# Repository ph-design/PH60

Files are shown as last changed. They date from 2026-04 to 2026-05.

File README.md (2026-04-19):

English Version | [中文版](README-zh_CN.md)

**[GitHub Repo](https://github.com/ph-design/PH60) | [Wiki](https://wiki.phdesign.cc/PH60/rev3_multi/) | [Discord](https://discord.gg/8UfQXcefPH) | [Taobao Store](https://shop268559013.taobao.com) | [QQ Group](https://qm.qq.com/q/OY0mIxSRs4) | [Customizer](https://custom.phdesign.cc)**

---

# PH60 Rev.3

**PH60 Rev.3** is a 60% tri-mode mechanical keyboard kit with an FDM 3D-printable case and the PH60 Rev.3 Multi PCB. This revision switches to the NRF52840 MCU with Bluetooth 5.3 and Nordic 2.4 GHz proprietary protocol (TBD), runs [ZMKs](https://github.com/ph-design/zmks) firmware (our fork of ZMK), and redesigns the case for wireless use and multi-layout compatibility.

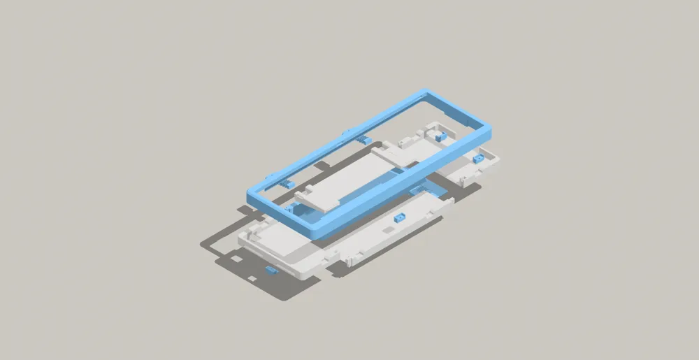
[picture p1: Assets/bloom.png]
PH60 Rev.3 Bloom


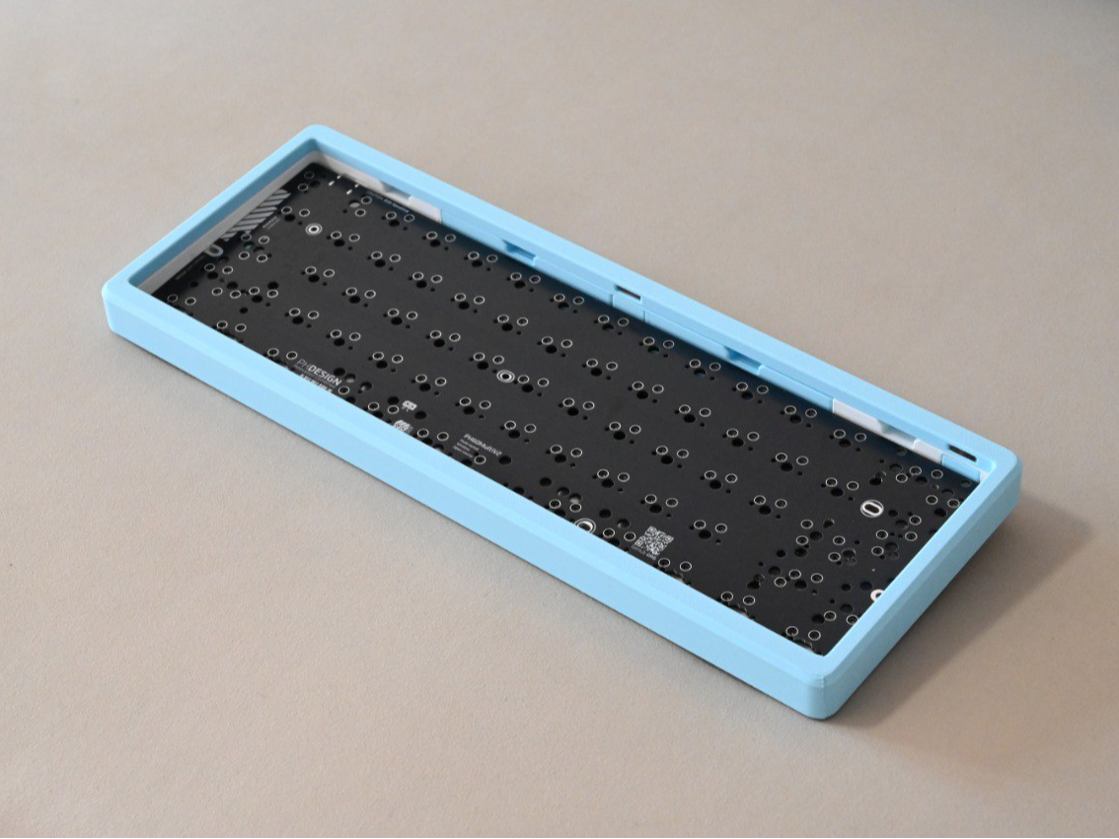
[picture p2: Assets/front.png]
PH60 Rev.3 Front


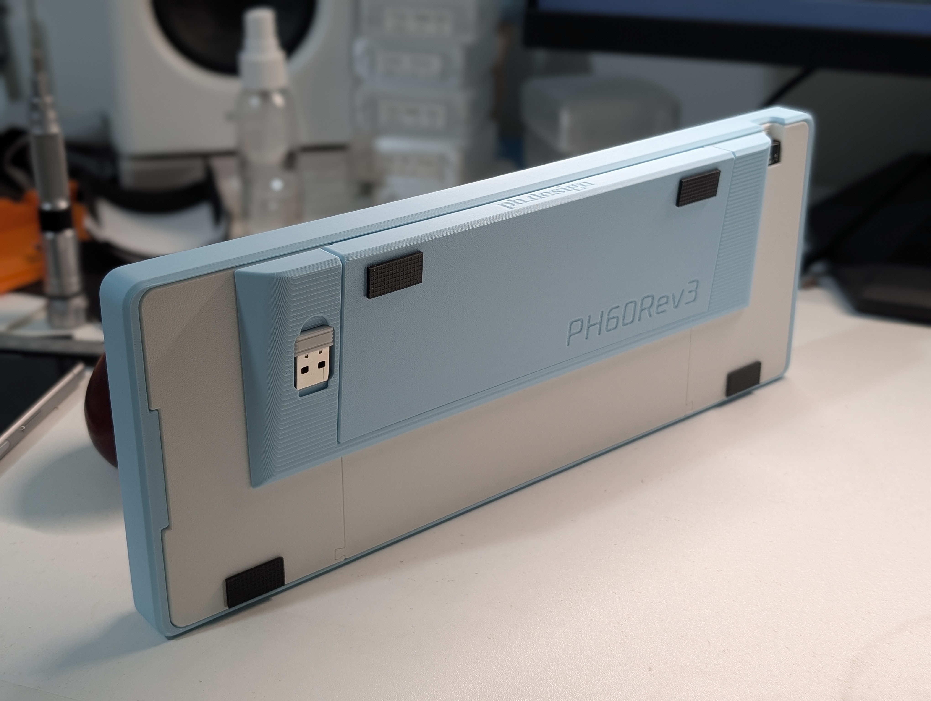
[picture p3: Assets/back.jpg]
PH60 Rev.3 Back


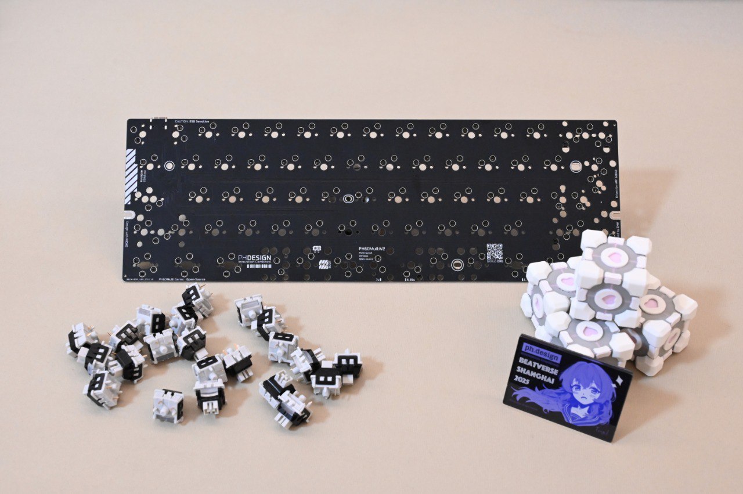
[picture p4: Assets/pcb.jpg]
PH60 Rev.3 PCB


## Features

### PCB

+ [Nordic NRF52840](https://www.nordicsemi.com/products/nrf52840) MCU, Bluetooth 5.3 + 2.4 GHz (TBD).
+ [ZMKs](https://github.com/ph-design/zmks) firmware with [ZMKs Studio](https://zmks.phdesign.cc/) for real-time keymap editing.
+ Multi-layout support — ANSI / ISO / WK / WKL / HHKB, plus split spacebar: 6.25u → 2.75u + 1u + 2.5u, 7u → 3u + 1u + 3u.
+ Battery powered, built-in battery connector.

> **Note on ANSI/ISO variants:** Rev.3 currently only ships the **Multi** layout PCB. The ANSI PCB in this repo is an early prototype with a fundamentally different design approach — there is no standalone ISO version. We may develop dedicated ANSI/ISO variants based on ZMKs in the future.

### Case

+ Designed for FDM 3D printing — printable on any printer with a bed ≥ 256 × 256 mm, no supports required.
+ Magnetic quick-release latches — tool-free disassembly.
+ O-ring gasket plate mount — firm, crisp feel without foam.
+ Modular battery tray and magnet drawers, fits up to 100 × 50 × 5 mm LiPo and 10 × 5 × 5 mm magnets.
+ Locking holder for wireless receivers, compatible with most commercial 2.4 GHz receiver housings.
+ Multiple outer case variants: Standard, WKL, HHKB (6u/7u), and split backspace options.

### Plates

+ Plates available for ANSI, ISO, WK, HHKB (6u/7u), LS64, EC60, and split-key variants.
+ More layouts added over time.

## What's new compared to Rev.2

| | Rev.2 | Rev.3 |
| --- | --- | --- |
| **MCU** | RP2040 | NRF52840 |
| **Connectivity** | USB only | USB + Bluetooth 5.3 + 2.4 GHz (TBD) |
| **Firmware** | QMK + VIA | ZMKs + ZMKs Studio |
| **Power** | USB powered | Battery powered |
| **Split spacebar** | Not supported | 6.25u & 7u split |
| **Case** | 3-piece modular | Magnetic quick-release, O-ring gasket |

## Customizer

Configure your PH60 Rev.3 with live 3D preview at [custom.phdesign.cc](https://custom.phdesign.cc).

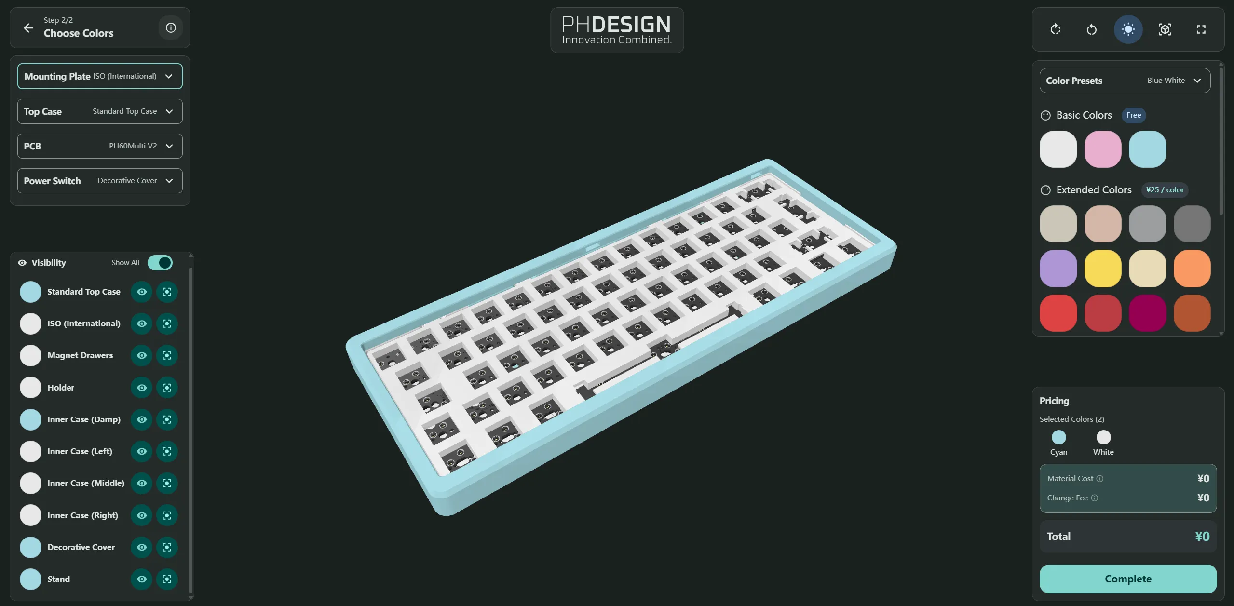
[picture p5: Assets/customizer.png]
PHD Customizer


---

## Project Structure

```
PH60 Rev.3
├── Assets/                         # Preview images
├── Case_Model_Rev3/                # Case 3D model files (STEP)
├── LICENSE
├── PCB_Model_Rev3/                 # PCB 3D model files
├── PCB_Rev3/
│   ├── ANSI/                       # ANSI variant (early prototype)
│   └── Multi/                      # Multi-layout variant (primary)
├── Plates_Rev3/                    # Plate files (STEP)
├── Production/
│   ├── PH60-Rev3-ANSI/             # ANSI production files
│   └── PH60-Rev3-Multi/            # Multi production files
├── README.md
└── README-zh_CN.md
```

## Printing Guide

The case prints well with default FDM settings. Recommended parameters for best results:

| Setting | Recommended | Notes |
| --- | --- | --- |
| Filament | PLA or PETG | High-temp materials increase warp risk |
| Layer height | 0.2 mm | Model designed around 0.2 mm |
| Wall count | 2 walls | — |
| Infill pattern | Gyroid | — |
| Infill density | 15% | — |
| Wall generator | Arachne | Improves print speed |
| Accurate outer wall | Enabled | Reduces visible layer lines |
| Support | Off | Designed for supportless printing |

Make sure the bed is leveled and clean before printing. Use adhesive on long parts like the top cover to prevent warping. Sand and clean prints for a better finish.

## Assembly

### Bill of Materials

| Item | Qty | Notes |
| --- | --- | --- |
| 3D printed case parts | 1 set | PLA or PETG recommended |
| PH60 Rev.3 Multi PCB | 1 | Pre-soldered SMD components |
| MX-compatible switches | 61+ | Varies by layout |
| Keycaps | 1 set | Compatible with 60% layout |
| LiPo battery (optional) | 1 | Recommended: 100 × 50 × 5 mm, Molex 1.25 mm connector |
| Magnets | 8 | Recommended: 10 × 5 × 3 mm, N52 |
| Silicone O-rings | 8 | OD 9 mm, cord 1.5 mm |
| Silicone anti-slip pads | 4 | Recommended: 20 × 10 × 2 mm |

For detailed assembly steps, refer to the [Wiki](https://wiki.phdesign.cc/PH60/rev3_multi/).

## Firmware

### Getting Firmware

- **GitHub Actions**: Download from the [ZMKs config repository](https://github.com/ph-design/ph_lite-zmk-config) Actions artifacts.
- **QQ Group**: Join [512933670](https://qm.qq.com/q/OY0mIxSRs4) for firmware files in group shared folder.

### Flashing Firmware

1. **Enter bootloader**: Press `FN + B + R`, or remove the spacebar keycap and double-tap the `BOOT` pads with tweezers.
2. **Flash**: The keyboard appears as a USB storage device. Copy the `.uf2` file to it — the keyboard reboots automatically.

### Keymap Customization

Visit [ZMKs Studio](https://zmks.phdesign.cc/) for real-time keymap editing.

## FAQ

**Q: Which 3D printers can print the Rev.3 case?**
A: Any FDM printer with a bed ≥ 256 × 256 mm that can print PLA or PETG.

**Q: Which layouts does the Rev.3 case support?**
A: ANSI, ISO, HHKB, WK, WKL, LS64, and EC60 (NIZ electrostatic capacitive). Plate designs are continuously updated.

**Q: Why is there no dedicated ANSI or ISO PCB?**
A: The early ANSI prototype has a fundamentally different design from the Multi PCB. We focused on Multi to support all layouts with a single board. Dedicated variants may come later based on ZMKs.

**Q: What battery and magnet sizes are supported?**
A: Up to 100 × 50 × 5 mm LiPo battery. Magnets: 10 × 5 × 3 mm (N52 recommended). The battery tray and magnet drawers can be modified for other sizes.

## Getting Help

- GitHub Issues: [ph-design/PH60](https://github.com/ph-design/PH60/issues)
- Discord: [discord.gg/phdesign](https://discord.gg/8UfQXcefPH)
- QQ Group: [512933670](https://qm.qq.com/q/OY0mIxSRs4)
- Wiki: [wiki.phdesign.cc](https://wiki.phdesign.cc/)

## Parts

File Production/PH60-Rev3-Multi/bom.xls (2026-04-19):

型号 | 封装 | 位号 | 元件编号
100k | 0402 | R2 | C25741
2k | 0402 | R3 | C4109
1.5p | 0402 | C24 | C1552
PRTR5V0U2X | SOT-143 | D1 | C5158049
1R | 0402 | R5,R6 | C17168
0R | 0402 | R4 | C17168
1u | 0402 | C16,C19,C23 | C52923
TPS2116DRL | SOT-583-8 | U4 | C3235557
FHW0402UC4N7JST | 0402 | L3 | C317941
nRF52840 | Nordic_AQFN-73-1EP_7x7mm_P0.5mm_2_Layer_Board | U2 | C190794
5K1 | 0402 | R7,R8 | C25905
DIODE | D_SOD-123 | D10,D11,D12,D13,D14,D14-1,D15,D16,D17,D18,D19,D2,D20,D21,D22,D23,D24,D25,D26,D27,D28,D29,D3,D30,D31,D32,D33,D34,D35,D36,D37,D38,D39,D4,D40,D41,D42,D43,D44,D45,D46,D47,D48,D49,D5,D50,D51,D52,D53,D54,D55,D56,D57,D58,D59,D6,D60,D61,D62,D63,D64,D65,D66,D67,D7,D8,D9 | C81598
Battery | Molex_PicoBlade_53261-0271_1x02-1MP_P1.25mm_Horizontal | BT1 | C2845379
32.768kHz | Crystal_SMD_3215-2Pin_3.2x1.5mm | X1 | C32346
Crystal_Generic | Crystal_SMD_2016-4Pin_2.0x1.6mm | X2 | C5339095
100n | 0402 | C1,C20,C21,C22 | C1525
12p | 0402 | C10,C14,C15,C8 | C1547
TP4057 | TSOT-23-6 | U1 | C725791
MCL1608S100MT | 0603 | L1,L2 | C51942
100p | 0402 | C4 | C1546
820p | 0402 | C2 | C1523
47n | 0603 | C17 | C1622
2.2u | 0402 | C9 | C12530
LQG15HS15NJ02D | 0402 | L6 | C86059
0.5p | 0402 | C12 | C40459
0.8p | 0402 | C13 | C40459
USB_C_Receptacle_USB2.0_16P | USB-C_16P_HandSolder | J3 | C393939
MX1A | SW_Hotswap_Kailh_MX_Plated_ISOEnter_90deg | S41-1 | C41430893
MX1A | SW_Hotswap_Kailh_MX_Plated_1.00u | S1,S10,S11,S12,S13,S14-1,S14-2,S16,S17,S18,S19,S2,S20,S21,S22,S23,S24,S25,S26,S27,S29,S3,S31,S32,S33,S34,S35,S36,S37,S38,S39,S4,S40,S41,S44,S45,S46,S47,S48,S49,S5,S50,S51,S52,S53,S54,S56,S58-1,S6,S63-1,S7,S8,S9 | C41430893
MX1A | SW_Hotswap_Kailh_MX_Plated_1.50u_90deg | S28 | C41430893
MX1A | SW_Hotswap_Kailh_MX_Plated_7.00u | S60-1 | C41430893
MX1A | SW_Hotswap_Kailh_MX_Plated_1.25u | S29-1,S43,S57,S59,S60,S61,S62,S63,S64,S65 | C41430893
MX1A | SW_Hotswap_Kailh_MX_Plated_1.75u | S30,S55 | C41430893
MX1A | SW_Hotswap_Kailh_MX_Plated_1.50u | S15,S57-1,S59-1,S62-1,S64-1 | C41430893
MX1A | SW_Hotswap_Kailh_MX_Plated_2.25u_90deg | S42 | C41430893
MX1A | SW_Hotswap_Kailh_MX_Plated_2.75u | S55-1,S60-1-B1 | C41430893
MX1A | SW_Hotswap_Kailh_MX_Plated_2.00u | S14 | C41430893
MX1A | SW_Hotswap_Kailh_MX_Plated_2.25u | S43-1,S60-1-A1 | C41430893
MX1A | SW_Hotswap_Kailh_MX_Plated_6.25u | S60-2 | C41430893
MX1A | SW_Hotswap_Kailh_MX_Plated_3.00u | S60-1-A2,S60-1-B2 | C41430893
330k | 0402 | R1 | C25778
4u7 | 0402 | C18,C3,C5,C6,C7 | C23733
4.7u | 0402 | C11 | C23733
Value | Footprint | Designator | NC
Conn_01x02_Pin | PinHeader_1x02_P2.00mm_Vertical | J1,J2 | NC
MX_stab | Stabilizer_Cherry_MX_7.00u | S60-X3 | NC
MX_stab | Stabilizer_Cherry_MX_6.25u | S60-X1 | NC
MX_stab | Stabilizer_Cherry_MX_2.00u | S14-X1,S29-X1,S41-X1,S41-X2,S55-X1,S60-X4,S60-X6 | NC

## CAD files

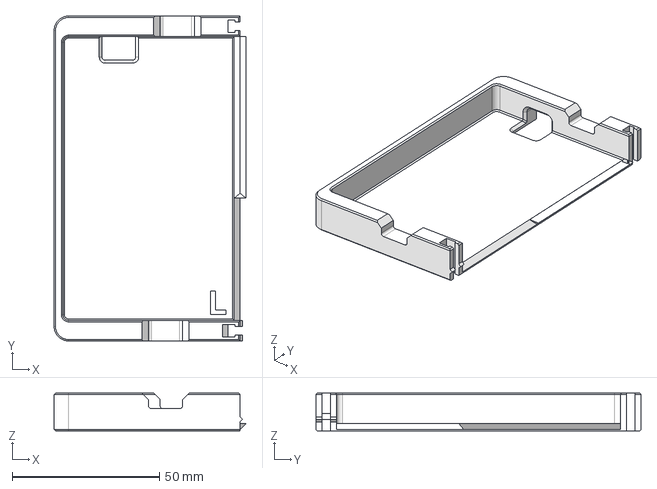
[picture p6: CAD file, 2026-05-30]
Case_Model_Rev3/inner_case_left.step
65.3 x 110.5 x 12.9 mm

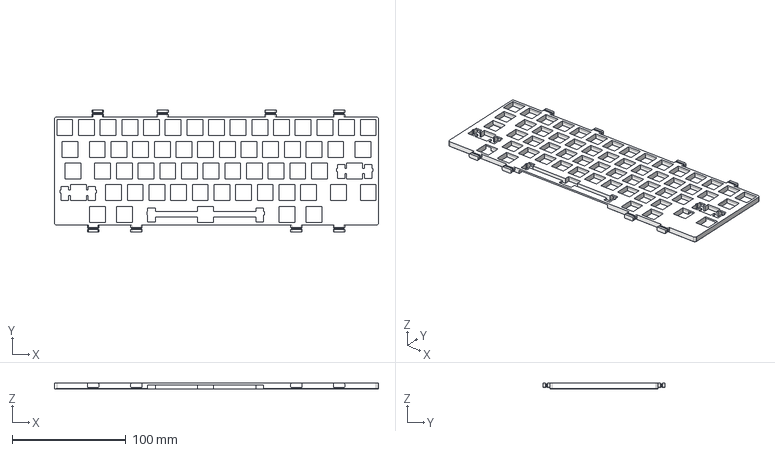
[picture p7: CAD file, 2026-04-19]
Plates_Rev3/plate_6u_hhkb.step
284.7 x 107.3 x 5.00 mm
plate
main_frame

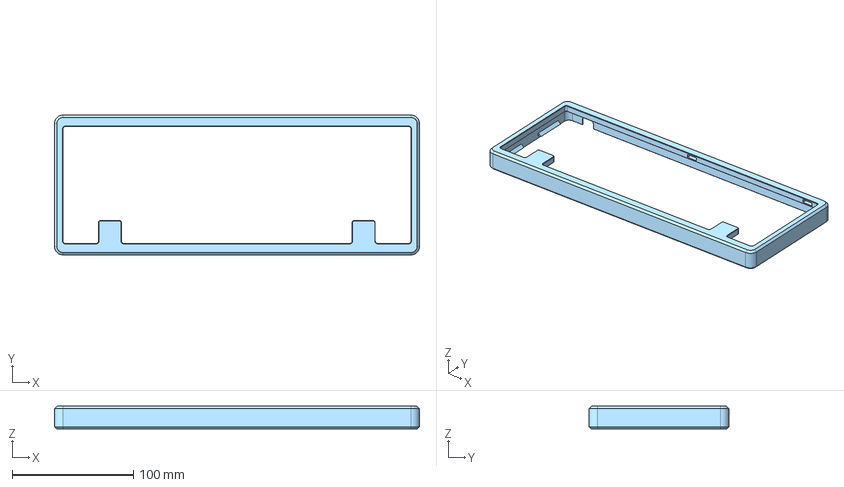
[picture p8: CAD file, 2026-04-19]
Case_Model_Rev3/outer_case_wkl.step
301.4 x 115.5 x 18.7 mm

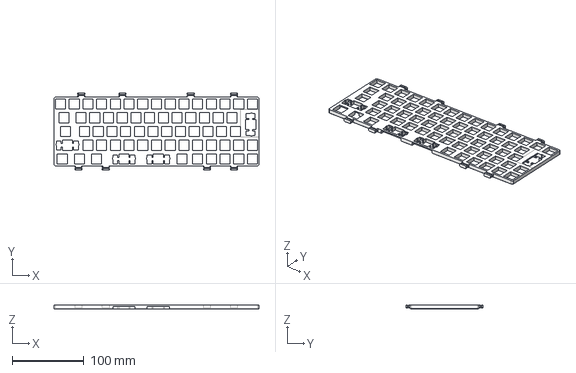
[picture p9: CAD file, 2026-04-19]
Plates_Rev3/plate_ls64_spilt_space_backspace_isoenter.step
284.7 x 107.3 x 5.00 mm

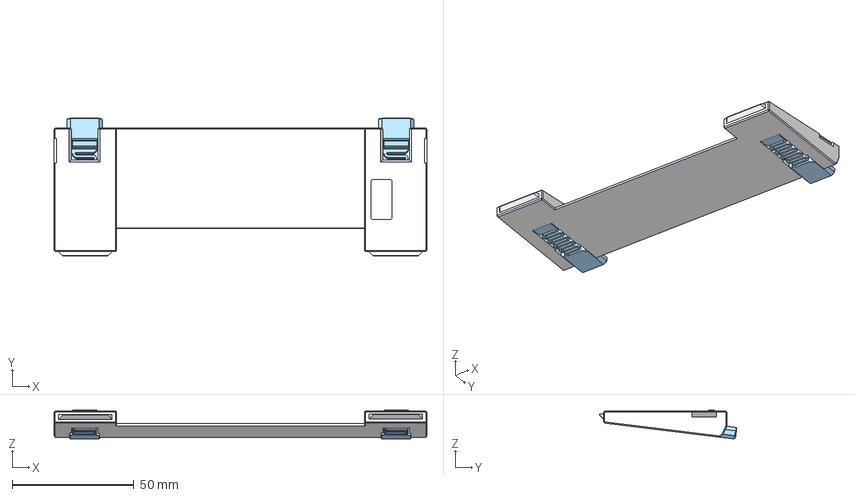
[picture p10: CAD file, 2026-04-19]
Case_Model_Rev3/battery_holder.step
153.1 x 56.5 x 11.9 mm

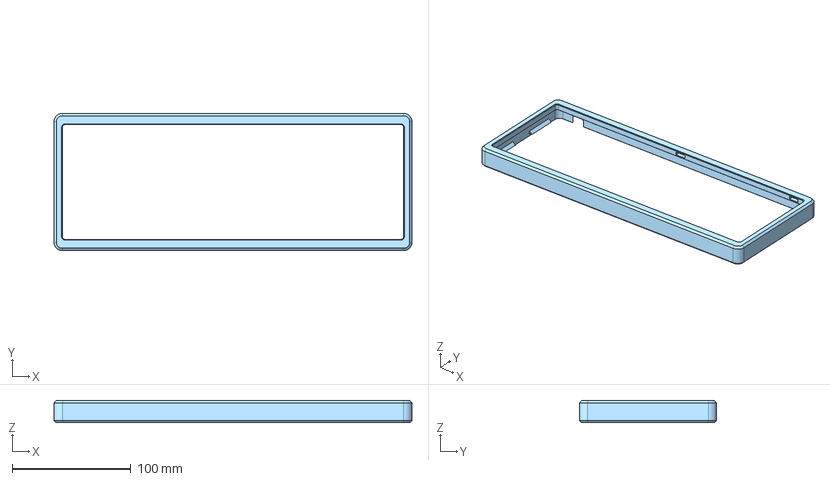
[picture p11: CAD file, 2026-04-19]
Case_Model_Rev3/outer_case.step
301.4 x 115.5 x 18.7 mm

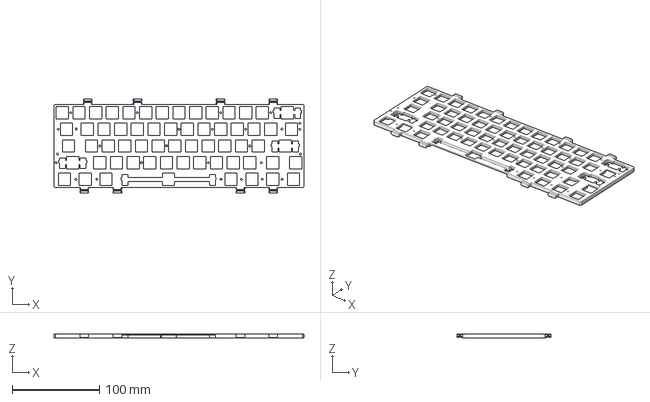
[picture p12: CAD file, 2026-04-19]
Plates_Rev3/plate_h60ec.step
285.7 x 107.3 x 5.00 mm
plate x 2

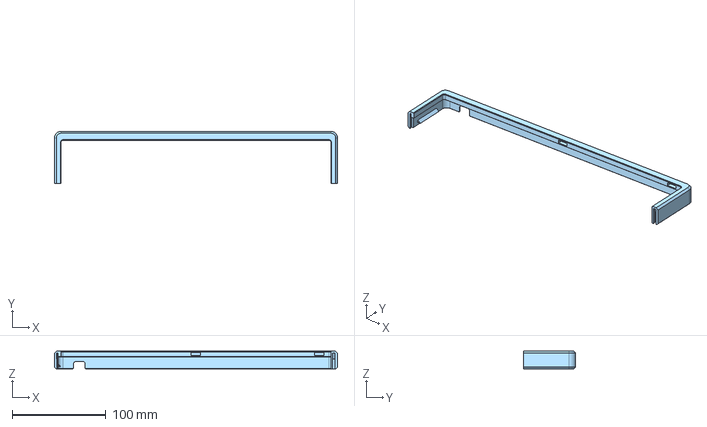
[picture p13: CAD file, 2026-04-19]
Case_Model_Rev3/outer_case_split_f.step
301.4 x 55.7 x 18.7 mm

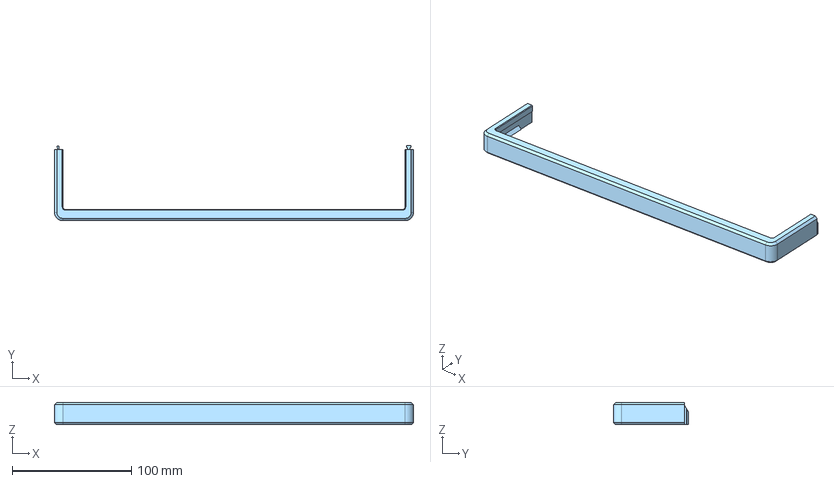
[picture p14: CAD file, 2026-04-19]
Case_Model_Rev3/outer_case_split_b.step
301.4 x 63.3 x 18.7 mm

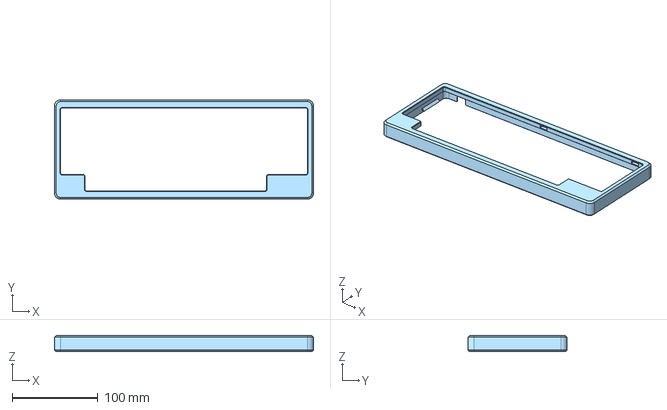
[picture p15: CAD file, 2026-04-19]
Case_Model_Rev3/outer_case_hhkb_6u.step
301.4 x 115.5 x 18.7 mm
plate
main_frame

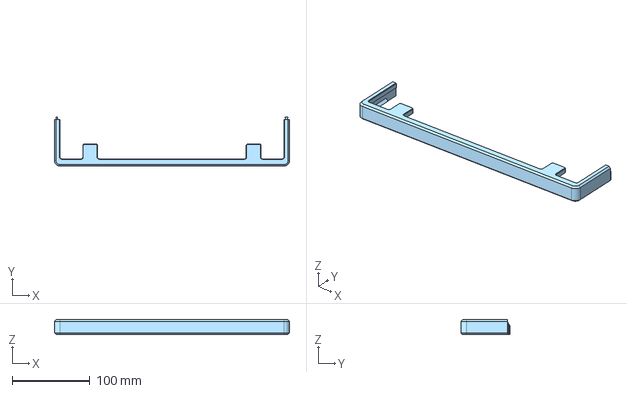
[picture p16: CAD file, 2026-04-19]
Case_Model_Rev3/outer_case_wkl_split_b.step
301.4 x 63.3 x 18.7 mm

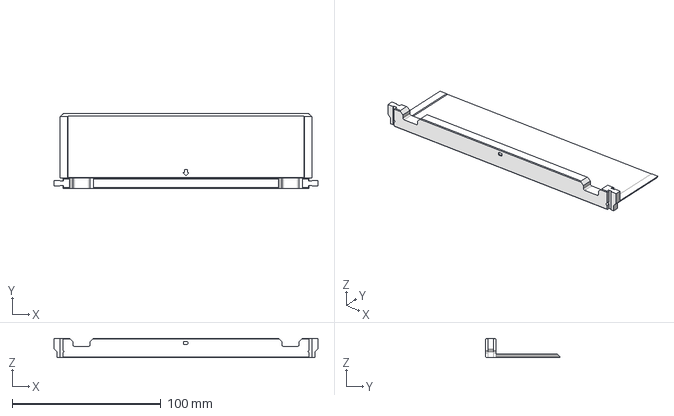
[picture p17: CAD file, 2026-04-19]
Case_Model_Rev3/inner_case_mid.step
177.7 x 50.4 x 12.9 mm

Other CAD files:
Plates_Rev3/plate_wk_split_backspace.step
Plates_Rev3/plate_7u_hhkb.step
Plates_Rev3/plate_ls64_ptg.step
Plates_Rev3/plate_ansi_split_rshift_backspace_space_0.step
Plates_Rev3/plate_ec60_ansi.step
Plates_Rev3/plate_non_shift_63.step
Case_Model_Rev3/inner_case_damp.step
Case_Model_Rev3/inner_case_right.step
Case_Model_Rev3/magnet_drawer.step
Case_Model_Rev3/outer_case_hhkb_6u_split_b.step
Case_Model_Rev3/outer_case_hhkb_7u.step
Case_Model_Rev3/outer_case_hhkb_7u_split_b.step
Case_Model_Rev3/stand.step
Plates_Rev3/plate_7u_hhkb_non_split_backspace.step
Plates_Rev3/plate_ansi.step
Plates_Rev3/plate_ansi_split_backspace_rshift.step
Plates_Rev3/plate_ansi_split_rshift_space_0.step
Plates_Rev3/plate_iso.step
Plates_Rev3/plate_ls64.step
Plates_Rev3/plate_wk.step

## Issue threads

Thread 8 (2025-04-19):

Print Volume

emolitor, 2025-04-19:
The documentation states that you need a 250x250 mm printer but I was able to print the models on a Prusa Core One (250x220mm) simply by printing the large side pieces vertically. While this might by slightly weaker due to layer adhesion I did test versions in PC and PETG and they are holding up fine so far.

nonameCCC, 2025-04-19:
Currently our design of the case was based on Bambu Lab printers, which have 256×256mm of heat bed area, so we gave out the restriction in the document. Smaller device may be able to print the case, but the strength won't be guaranteed.

Closed 2025-04-20.

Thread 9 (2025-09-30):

Plate mount stabilizer clarification

pixil98, 2025-09-30:
After printing this board and talking to MAltmann on Discord, it was clarified that the "thick" plates that are available on [Makerworld](https://makerworld.com/en/models/808113-ph60-a-fully-printable-60-layout-keyboard-case) (and presumably other locations) only support plate mount stabilizers. Can these locations be updated to clarify that they only support plate mount stabilizers? I couldn't find that documented anywhere.

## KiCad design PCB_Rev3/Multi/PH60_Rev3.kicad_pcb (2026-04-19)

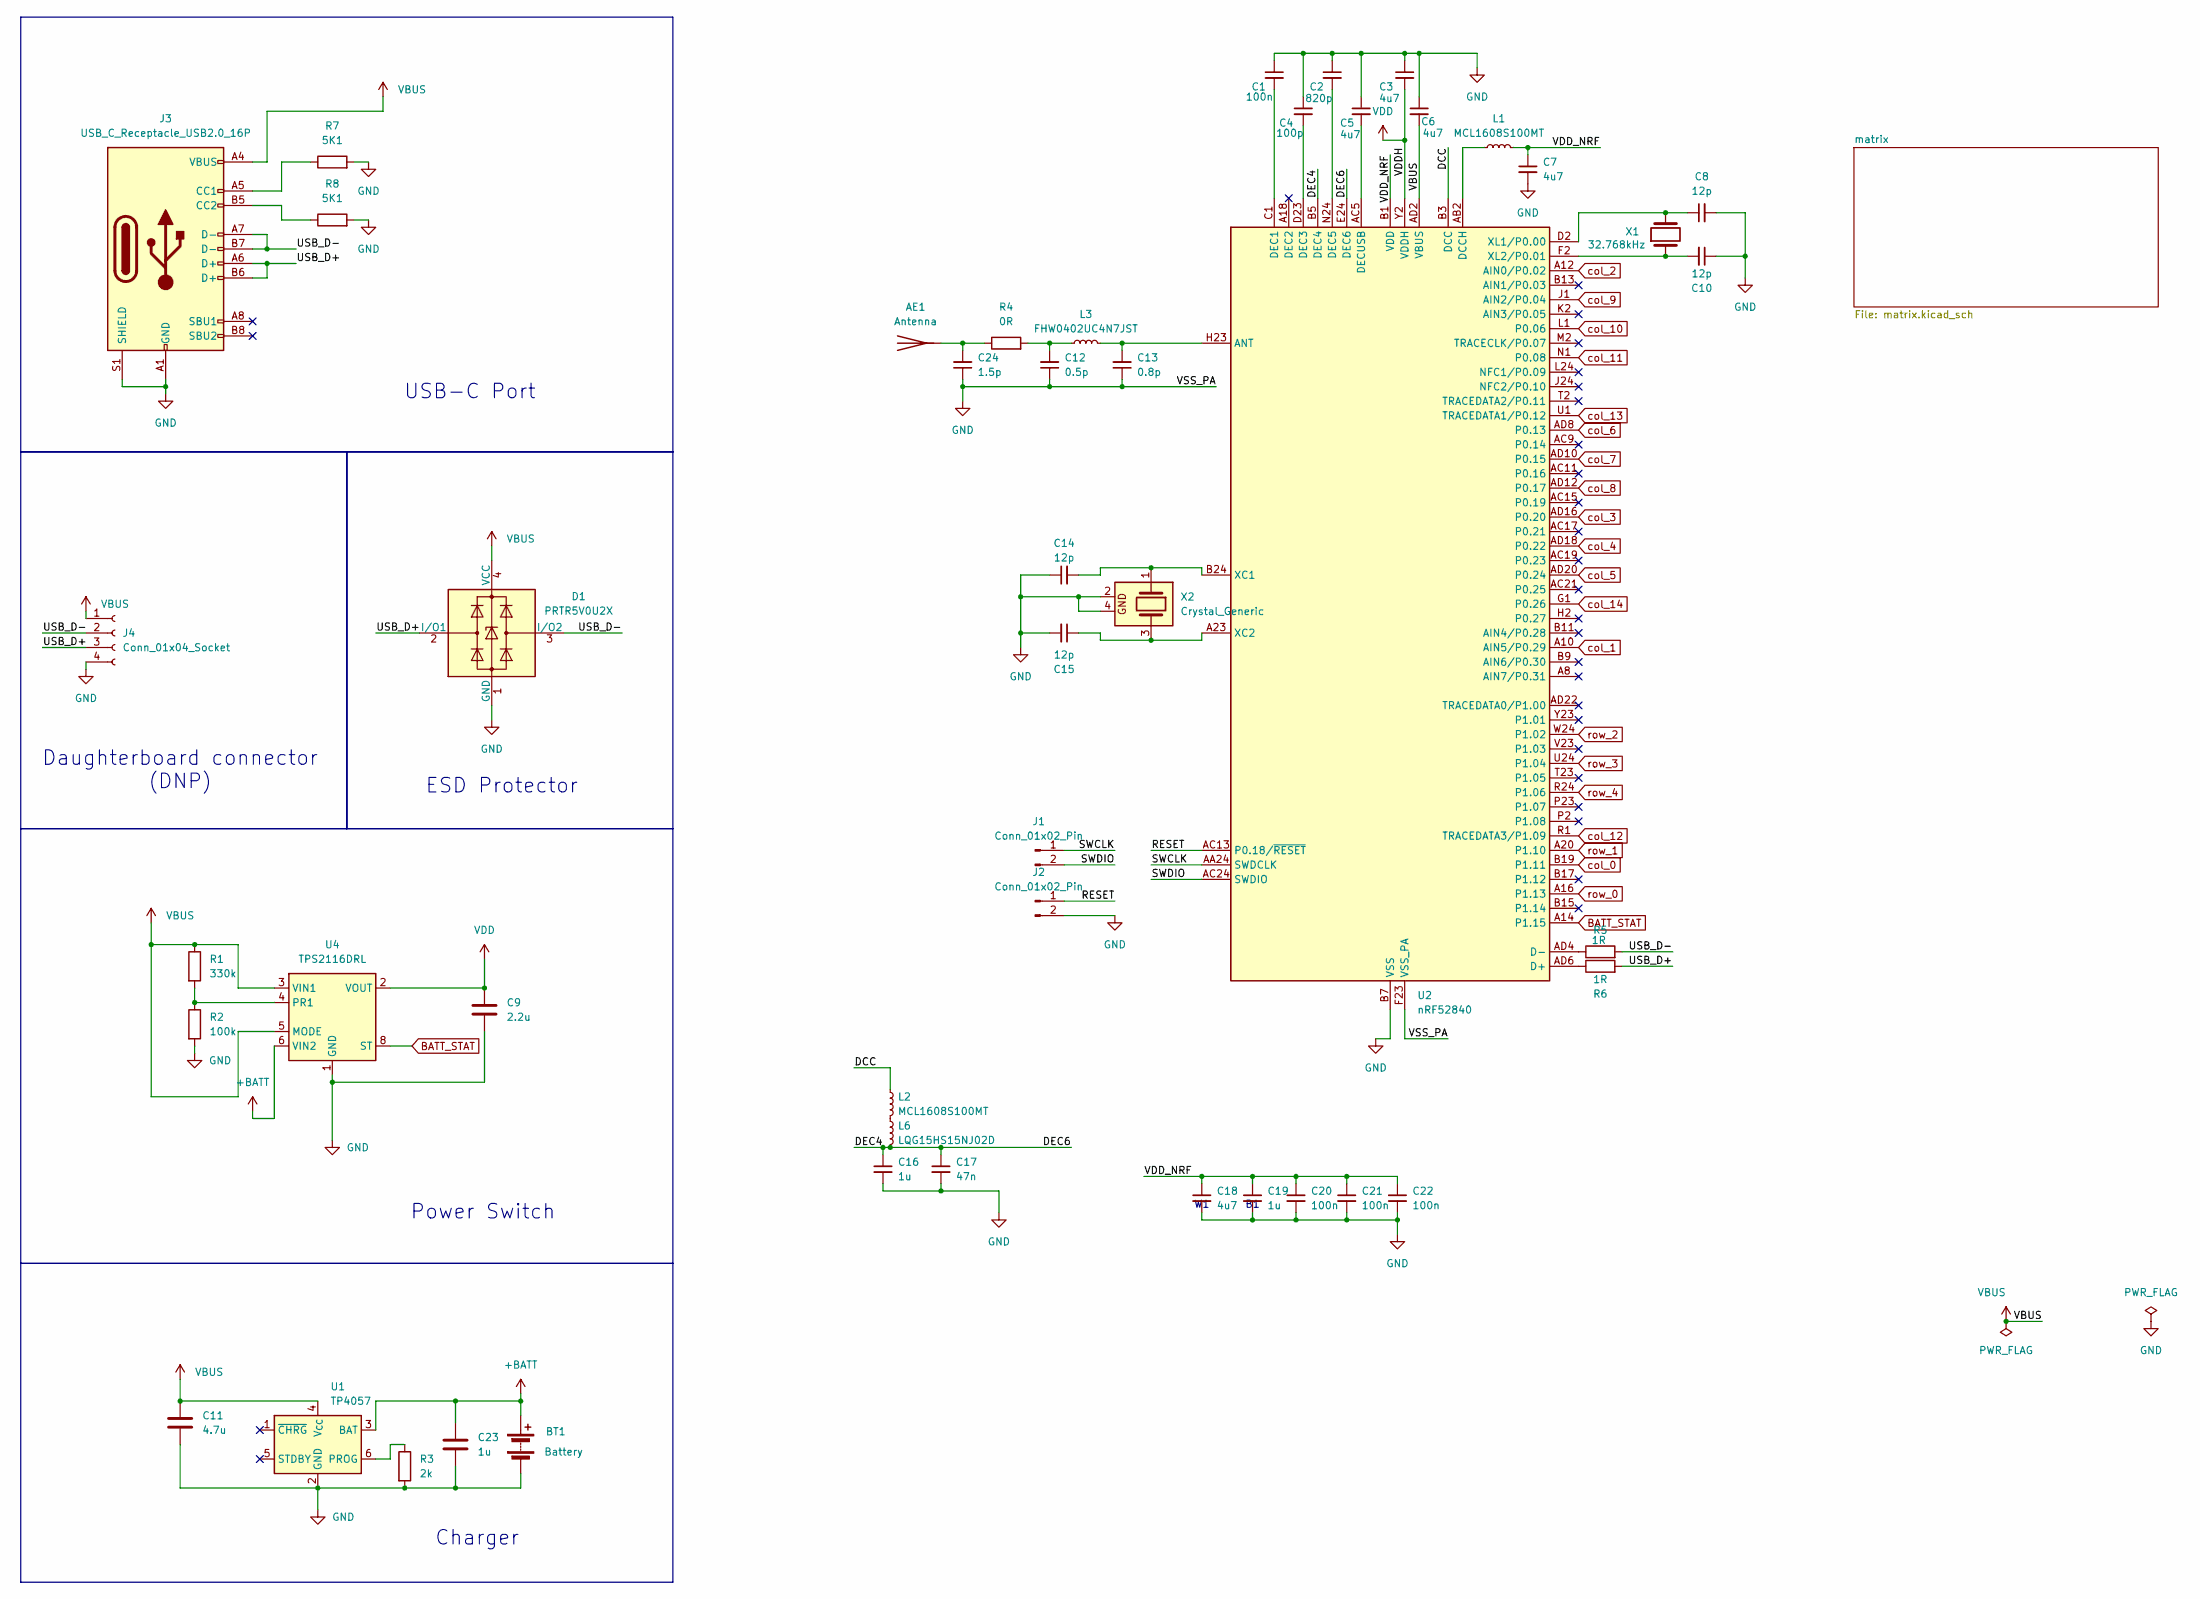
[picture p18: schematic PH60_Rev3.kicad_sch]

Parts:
AE1: Antenna; nrf52_ant_1.6mm
BT1: Battery; Molex_PicoBlade_53261-0271_1x02-1MP_P1.25mm_Horizontal
C1, C20, C21, C22: 100n; C_0402_1005Metric
C2: 820p; C_0402_1005Metric
C3, C5, C6, C7, C18: 4u7; C_0402_1005Metric
C4: 100p; C_0402_1005Metric
C8, C10, C14, C15: 12p; C_0402_1005Metric
C9: 2.2u; C_0402_1005Metric
C11: 4.7u; C_0402_1005Metric
C12: 0.5p; C_0402_1005Metric
C13: 0.8p; C_0402_1005Metric
C16, C19, C23: 1u; C_0402_1005Metric
C17: 47n; C_0603_1608Metric
C24: 1.5p; C_0402_1005Metric
D1: PRTR5V0U2X; SOT-143
J1, J2: Conn_01x02_Pin; PinHeader_1x02_P2.00mm_Vertical
J3: USB_C_Receptacle_USB2.0_16P; USB-C_16P_HandSolder
J4: Conn_01x04_Socket; Molex_Pico-EZmate_78171-0004_1x04-1MP_P1.20mm_Vertical
L1, L2: MCL1608S100MT; L_0603_1608Metric
L3: FHW0402UC4N7JST; L_0402_1005Metric
L6: LQG15HS15NJ02D; L_0402_1005Metric
R1: 330k; R_0402_1005Metric
R2: 100k; R_0402_1005Metric
R3: 2k; R_0402_1005Metric
R4: 0R; C_0402_1005Metric
R5, R6: 1R; C_0402_1005Metric
R7, R8: 5K1; R_0402_1005Metric
U1: TP4057; TSOT-23-6
U2: nRF52840; Nordic_AQFN-73-1EP_7x7mm_P0.5mm_2_Layer_Board
U4: TPS2116DRL; SOT-583-8
X1: 32.768kHz; Crystal_SMD_3215-2Pin_3.2x1.5mm
X2: Crystal_Generic; Crystal_SMD_2016-4Pin_2.0x1.6mm

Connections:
+BATT: BT1.1 (+), C23.1, U1.3 (BAT), U4.6 (VIN2)
/DCC: L2.1, U2.B3 (DCC)
/DEC4: C16.1, C17.1, L6.2, U2.B5 (DEC4), U2.E24 (DEC6)
/RESET: J2.1, U2.AC13 (P0.18/~RESET)
/SWCLK: J1.1, U2.AA24 (SWDCLK)
/SWDIO: J1.2, U2.AC24 (SWDIO)
/USB_D+: D1.2 (I/O1), J3.A6 (D+), J3.B6 (D+), J4.3, R6.2
/USB_D-: D1.3 (I/O2), J3.A7 (D-), J3.B7 (D-), J4.2, R5.2
/VDD_NRF: C7.1, C18.1, C19.1, C20.1, C21.1, C22.1, L1.2, U2.A22 (VDD), U2.AD14 (VDD), U2.AD23 (VDD), U2.B1 (VDD), U2.W1 (VDD)
BATT_STAT: U2.A14 (P1.15), U4.8 (ST)
GND: BT1.2 (-), C1.1, C2.1, C3.1, C4.1, C5.1, C6.1, C7.2, C8.2, C9.2, C10.1, C11.2, C12.1, C13.1, C14.1, C15.2, C16.2, C17.2, C18.2, C19.2, C20.2, C21.2, C22.2, C23.2, C24.1, D1.1 (GND), J2.2, J3.A1 (GND), J3.A12 (GND), J3.B1 (GND), J3.B12 (GND), J3.S1 (SHIELD), J4.4, R2.2, R3.2, R7.2, R8.2, U1.2 (GND), U2.B7 (VSS), U2.EP (VSS), U2.F23 (VSS_PA), U4.1 (GND), X2.2, X2.4
unnamed: AE1.1 (A), C24.2, R4.1
unnamed: C12.2, L3.1, R4.2
unnamed: J3.A5 (CC1), R7.1
unnamed: J3.B5 (CC2), R8.1
unnamed: L2.2, L6.1
unnamed: R3.1, U1.6 (PROG)
unnamed: C13.2, L3.2, U2.H23 (ANT)
unnamed: R6.1, U2.AD6 (D+)
unnamed: R5.1, U2.AD4 (D-)
unnamed: L1.1, U2.AB2 (DCCH)
unnamed: C1.2, U2.C1 (DEC1)
unnamed: C4.2, U2.D23 (DEC3)
unnamed: C2.2, U2.N24 (DEC5)
unnamed: C5.2, U2.AC5 (DECUSB)
unnamed: C14.2, U2.B24 (XC1), X2.1
unnamed: C15.1, U2.A23 (XC2), X2.3
unnamed: C8.1, U2.D2 (XL1/P0.00), X1.2
unnamed: C10.2, U2.F2 (XL2/P0.01), X1.1
unnamed: R1.2, R2.1, U4.4 (PR1)
VBUS: C6.2, C11.1, D1.4 (VCC), J3.A4 (VBUS), J3.A9 (VBUS), J3.B4 (VBUS), J3.B9 (VBUS), J4.1, R1.1, U1.4 (V_{CC}), U2.AD2 (VBUS), U4.3 (VIN1), U4.5 (MODE)
VDD: C3.2, C9.1, U2.Y2 (VDDH), U4.2 (VOUT), U4.7 (VOUT)
col_0: U2.B19 (P1.11); also elsewhere on the board
col_1: U2.A10 (AIN5/P0.29); also elsewhere on the board
col_2: U2.A12 (AIN0/P0.02); also elsewhere on the board
col_3: U2.AD16 (P0.20); also elsewhere on the board
col_4: U2.AD18 (P0.22); also elsewhere on the board
col_5: U2.AD20 (P0.24); also elsewhere on the board
col_6: U2.AD8 (P0.13); also elsewhere on the board
col_7: U2.AD10 (P0.15); also elsewhere on the board
col_8: U2.AD12 (P0.17); also elsewhere on the board
col_9: U2.J1 (AIN2/P0.04); also elsewhere on the board
col_10: U2.L1 (P0.06); also elsewhere on the board
col_11: U2.N1 (P0.08); also elsewhere on the board
col_12: U2.R1 (TRACEDATA3/P1.09); also elsewhere on the board
col_13: U2.U1 (TRACEDATA1/P0.12); also elsewhere on the board
col_14: U2.G1 (P0.26); also elsewhere on the board
row_0: U2.A16 (P1.13); also elsewhere on the board
row_1: U2.A20 (P1.10); also elsewhere on the board
row_2: U2.W24 (P1.02); also elsewhere on the board
row_3: U2.U24 (P1.04); also elsewhere on the board
row_4: U2.R24 (P1.06); also elsewhere on the board

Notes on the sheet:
ESD Protector
USB-C Port
Charger
Daughterboard connector (DNP)
Power Switch

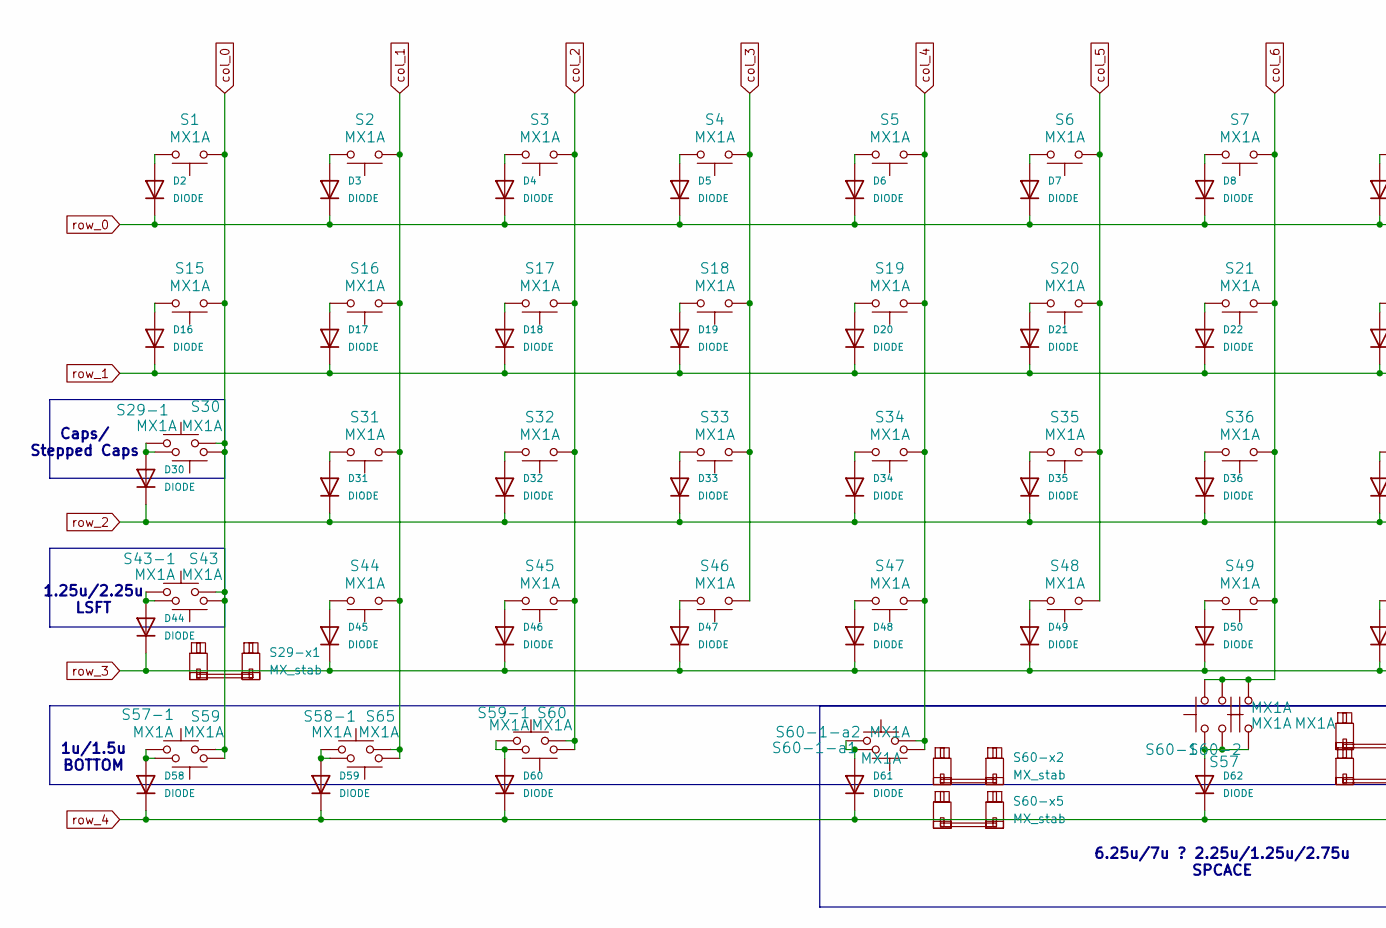
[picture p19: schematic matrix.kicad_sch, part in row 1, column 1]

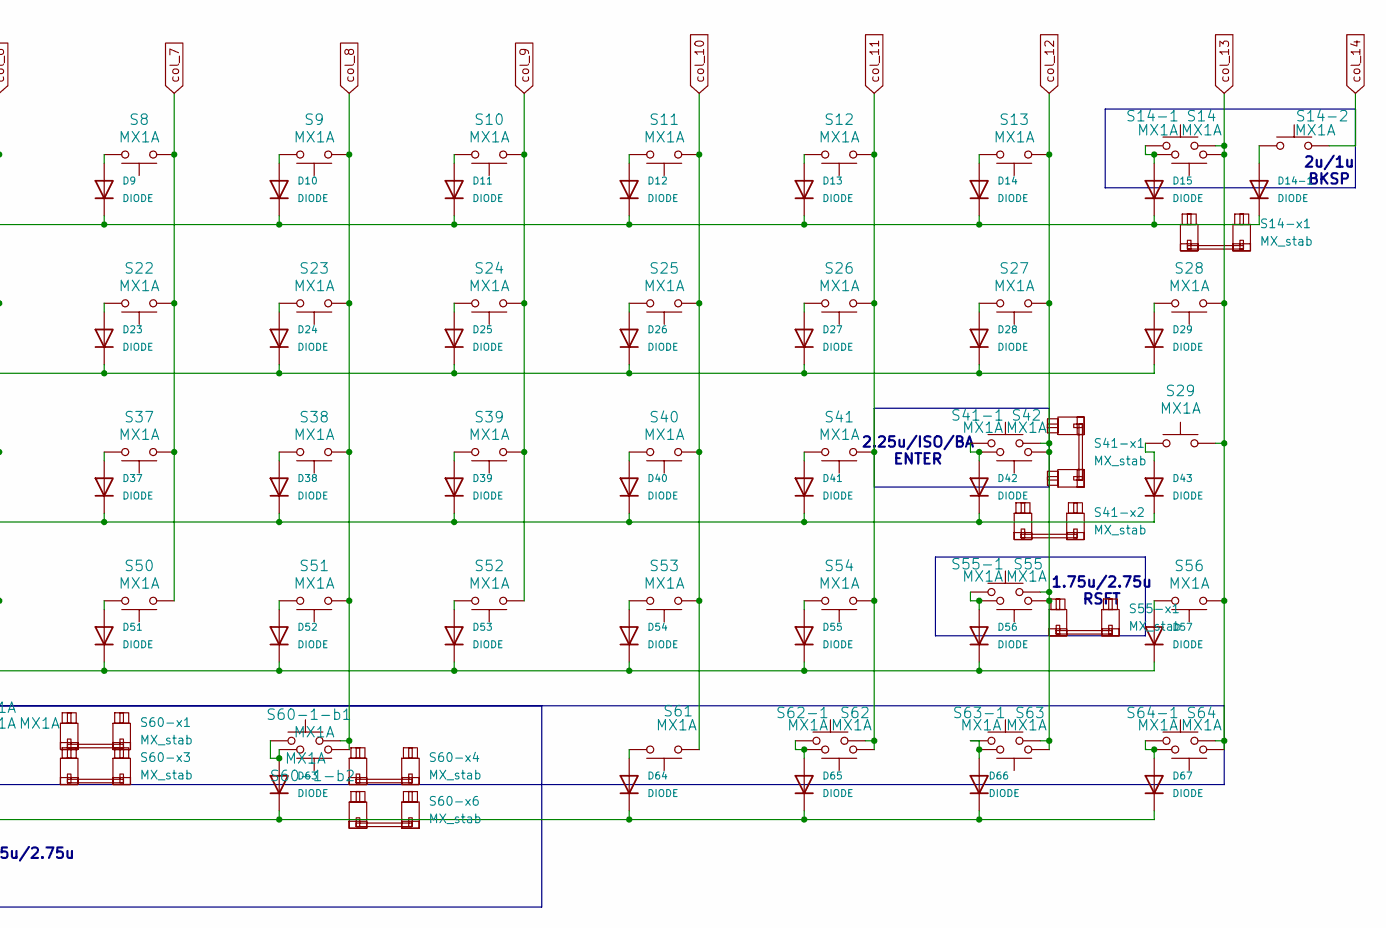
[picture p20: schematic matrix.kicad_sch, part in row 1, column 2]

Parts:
D2, D3, D4, D5, D6, D7, D8, D9, D10, D11, D12, D13, D14, D14-1, D15, D16, D17, D18, D19, D20, D21, D22, D23, D24, D25, D26, D27, D28, D29, D30, D31, D32, D33, D34, D35, D36, D37, D38, D39, D40, D41, D42, D43, D44, D45, D46, D47, D48, D49, D50, D51, D52, D53, D54, D55, D56, D57, D58, D59, D60, D61, D62, D63, D64, D65, D66, D67: DIODE; D_SOD-123
S1, S2, S3, S4, S5, S6, S7, S8, S9, S10, S11, S12, S13, S14-1, S14-2, S16, S17, S18, S19, S20, S21, S22, S23, S24, S25, S26, S27, S29, S31, S32, S33, S34, S35, S36, S37, S38, S39, S40, S41, S44, S45, S46, S47, S48, S49, S50, S51, S52, S53, S54, S56, S58-1, S63-1: MX1A; SW_Hotswap_Kailh_MX_Plated_1.00u
S14: MX1A; SW_Hotswap_Kailh_MX_Plated_2.00u
S14-x1, S29-x1, S41-x1, S41-x2, S55-x1, S60-x2, S60-x4, S60-x5, S60-x6: MX_stab; Stabilizer_Cherry_MX_2.00u
S15, S57-1, S59-1, S62-1, S64-1: MX1A; SW_Hotswap_Kailh_MX_Plated_1.50u
S28: MX1A; SW_Hotswap_Kailh_MX_Plated_1.50u_90deg
S29-1, S43, S57, S59, S60, S61, S62, S63, S64, S65: MX1A; SW_Hotswap_Kailh_MX_Plated_1.25u
S30, S55: MX1A; SW_Hotswap_Kailh_MX_Plated_1.75u
S41-1: MX1A; SW_Hotswap_Kailh_MX_Plated_ISOEnter_90deg
S42: MX1A; SW_Hotswap_Kailh_MX_Plated_2.25u_90deg
S43-1, S60-1-a1: MX1A; SW_Hotswap_Kailh_MX_Plated_2.25u
S55-1, S60-1-b1: MX1A; SW_Hotswap_Kailh_MX_Plated_2.75u
S60-1: MX1A; SW_Hotswap_Kailh_MX_Plated_7.00u
S60-1-a2, S60-1-b2: MX1A; SW_Hotswap_Kailh_MX_Plated_3.00u
S60-2: MX1A; SW_Hotswap_Kailh_MX_Plated_6.25u
S60-x1: MX_stab; Stabilizer_Cherry_MX_6.25u
S60-x3: MX_stab; Stabilizer_Cherry_MX_7.00u

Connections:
unnamed: D2.2 (A), S1.1
unnamed: D3.2 (A), S2.1
unnamed: D4.2 (A), S3.1
unnamed: D5.2 (A), S4.1
unnamed: D6.2 (A), S5.1
unnamed: D7.2 (A), S6.1
unnamed: D8.2 (A), S7.1
unnamed: D9.2 (A), S8.1
unnamed: D10.2 (A), S9.1
unnamed: D11.2 (A), S10.1
unnamed: D12.2 (A), S11.1
unnamed: D13.2 (A), S12.1
unnamed: D14-1.2 (A), S14-2.2
unnamed: D14.2 (A), S13.1
unnamed: D15.2 (A), S14.1, S14-1.2
unnamed: D16.2 (A), S15.1
unnamed: D17.2 (A), S16.1
unnamed: D18.2 (A), S17.1
unnamed: D19.2 (A), S18.1
unnamed: D20.2 (A), S19.1
unnamed: D21.2 (A), S20.1
unnamed: D22.2 (A), S21.1
unnamed: D23.2 (A), S22.1
unnamed: D24.2 (A), S23.1
unnamed: D25.2 (A), S24.1
unnamed: D26.2 (A), S25.1
unnamed: D27.2 (A), S26.1
unnamed: D28.2 (A), S27.1
unnamed: D29.2 (A), S28.1
unnamed: D30.2 (A), S29-1.2, S30.1
unnamed: D31.2 (A), S31.1
unnamed: D32.2 (A), S32.1
unnamed: D33.2 (A), S33.1
unnamed: D34.2 (A), S34.1
unnamed: D35.2 (A), S35.1
unnamed: D36.2 (A), S36.1
unnamed: D37.2 (A), S37.1
unnamed: D38.2 (A), S38.1
unnamed: D39.2 (A), S39.1
unnamed: D40.2 (A), S40.1
unnamed: D41.2 (A), S41.1
unnamed: D42.2 (A), S41-1.2, S42.1
unnamed: D43.2 (A), S29.2
unnamed: D44.2 (A), S43.1, S43-1.2
unnamed: D45.2 (A), S44.1
unnamed: D46.2 (A), S45.1
unnamed: D47.2 (A), S46.1
unnamed: D48.2 (A), S47.1
unnamed: D49.2 (A), S48.1
unnamed: D50.2 (A), S49.1
unnamed: D51.2 (A), S50.1
unnamed: D52.2 (A), S51.1
unnamed: D53.2 (A), S52.1
unnamed: D54.2 (A), S53.1
unnamed: D55.2 (A), S54.1
unnamed: D56.2 (A), S55.1, S55-1.2
unnamed: D57.2 (A), S56.1
unnamed: D58.2 (A), S57-1.1, S59.2
unnamed: D59.2 (A), S58-1.2, S65.1
unnamed: D60.2 (A), S59-1.2, S60.1
unnamed: D61.2 (A), S60-1-a1.1, S60-1-a2.2
unnamed: D62.2 (A), S57.1, S60-1.2, S60-2.2
unnamed: D63.2 (A), S60-1-b1.1, S60-1-b2.2
unnamed: D64.2 (A), S61.1
unnamed: D65.2 (A), S62.1, S62-1.2
unnamed: D66.2 (A), S63.1, S63-1.2
unnamed: D67.2 (A), S64.1, S64-1.2
col_0: S1.2, S15.2, S29-1.1, S30.2, S43.2, S43-1.1, S57-1.2, S59.1; also elsewhere on the board
col_1: S2.2, S16.2, S31.2, S44.2, S58-1.1, S65.2; also elsewhere on the board
col_2: S3.2, S17.2, S32.2, S45.2, S59-1.1, S60.2; also elsewhere on the board
col_3: S4.2, S18.2, S33.2, S46.2; also elsewhere on the board
col_4: S5.2, S19.2, S34.2, S47.2, S60-1-a1.2, S60-1-a2.1; also elsewhere on the board
col_5: S6.2, S20.2, S35.2, S48.2; also elsewhere on the board
col_6: S7.2, S21.2, S36.2, S49.2, S57.2, S60-1.1, S60-2.1; also elsewhere on the board
col_7: S8.2, S22.2, S37.2, S50.2; also elsewhere on the board
col_8: S9.2, S23.2, S38.2, S51.2, S60-1-b1.2, S60-1-b2.1; also elsewhere on the board
col_9: S10.2, S24.2, S39.2, S52.2; also elsewhere on the board
col_10: S11.2, S25.2, S40.2, S53.2, S61.2; also elsewhere on the board
col_11: S12.2, S26.2, S41.2, S54.2, S62.2, S62-1.1; also elsewhere on the board
col_12: S13.2, S27.2, S41-1.1, S42.2, S55.2, S55-1.1, S63.2, S63-1.1; also elsewhere on the board
col_13: S14.2, S14-1.1, S28.2, S29.1, S56.2, S64.2, S64-1.1; also elsewhere on the board
col_14: S14-2.1; also elsewhere on the board
row_0: D2.1 (K), D3.1 (K), D4.1 (K), D5.1 (K), D6.1 (K), D7.1 (K), D8.1 (K), D9.1 (K), D10.1 (K), D11.1 (K), D12.1 (K), D13.1 (K), D14.1 (K), D14-1.1 (K), D15.1 (K); also elsewhere on the board
row_1: D16.1 (K), D17.1 (K), D18.1 (K), D19.1 (K), D20.1 (K), D21.1 (K), D22.1 (K), D23.1 (K), D24.1 (K), D25.1 (K), D26.1 (K), D27.1 (K), D28.1 (K), D29.1 (K); also elsewhere on the board
row_2: D30.1 (K), D31.1 (K), D32.1 (K), D33.1 (K), D34.1 (K), D35.1 (K), D36.1 (K), D37.1 (K), D38.1 (K), D39.1 (K), D40.1 (K), D41.1 (K), D42.1 (K), D43.1 (K); also elsewhere on the board
row_3: D44.1 (K), D45.1 (K), D46.1 (K), D47.1 (K), D48.1 (K), D49.1 (K), D50.1 (K), D51.1 (K), D52.1 (K), D53.1 (K), D54.1 (K), D55.1 (K), D56.1 (K), D57.1 (K); also elsewhere on the board
row_4: D58.1 (K), D59.1 (K), D60.1 (K), D61.1 (K), D62.1 (K), D63.1 (K), D64.1 (K), D65.1 (K), D66.1 (K), D67.1 (K); also elsewhere on the board

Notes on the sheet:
2.25u/ISO/BA ENTER
6.25u/7u ? 2.25u/1.25u/2.75u SPCACE
Caps/ Stepped Caps
2u/1u BKSP
1.75u/2.75u RSFT
1.25u/2.25u LSFT
1u/1.5u BOTTOM

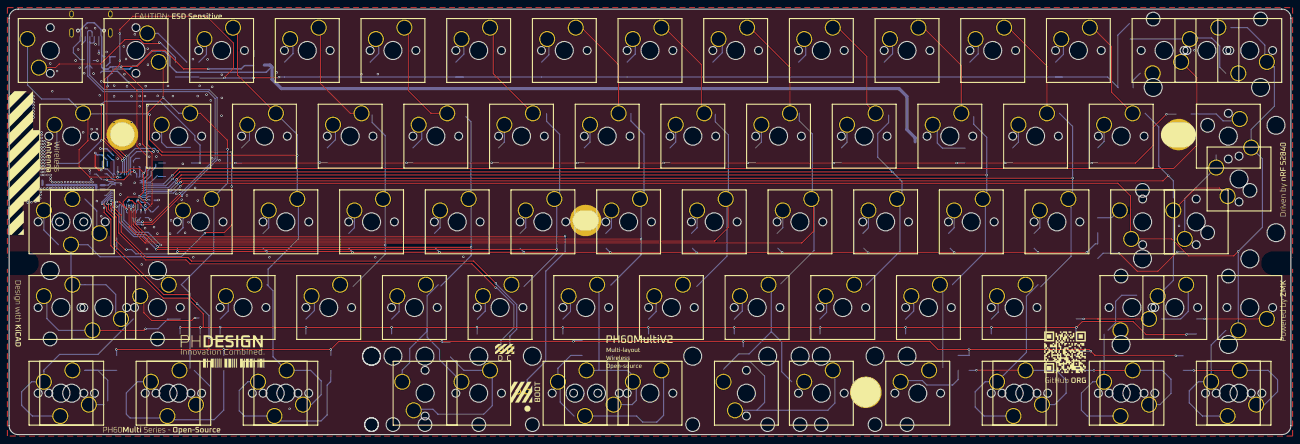
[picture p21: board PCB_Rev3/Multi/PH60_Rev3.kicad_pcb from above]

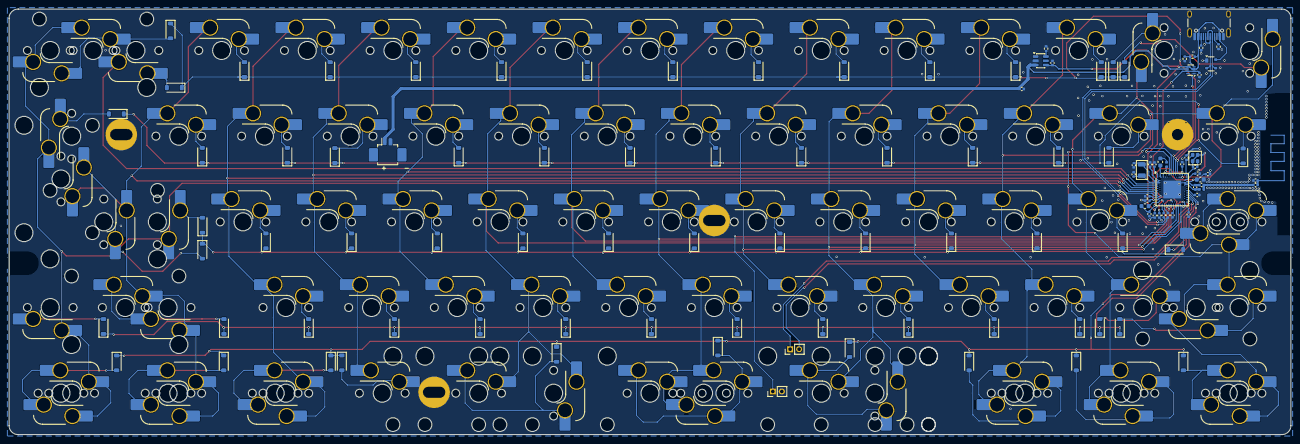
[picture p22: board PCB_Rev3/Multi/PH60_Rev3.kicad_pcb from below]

Board: 2 copper layers, 285.0 x 94.6 mm, 213 parts (114 on the bottom side), 119 nets.

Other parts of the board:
HOLE: VAL**; PKRH
HOLE#2, HOLE#6: VAL**; PKRH
HOLE#3, HOLE#5: VAL**; PKRHSL
HOLE#4: VAL**; PKRHC

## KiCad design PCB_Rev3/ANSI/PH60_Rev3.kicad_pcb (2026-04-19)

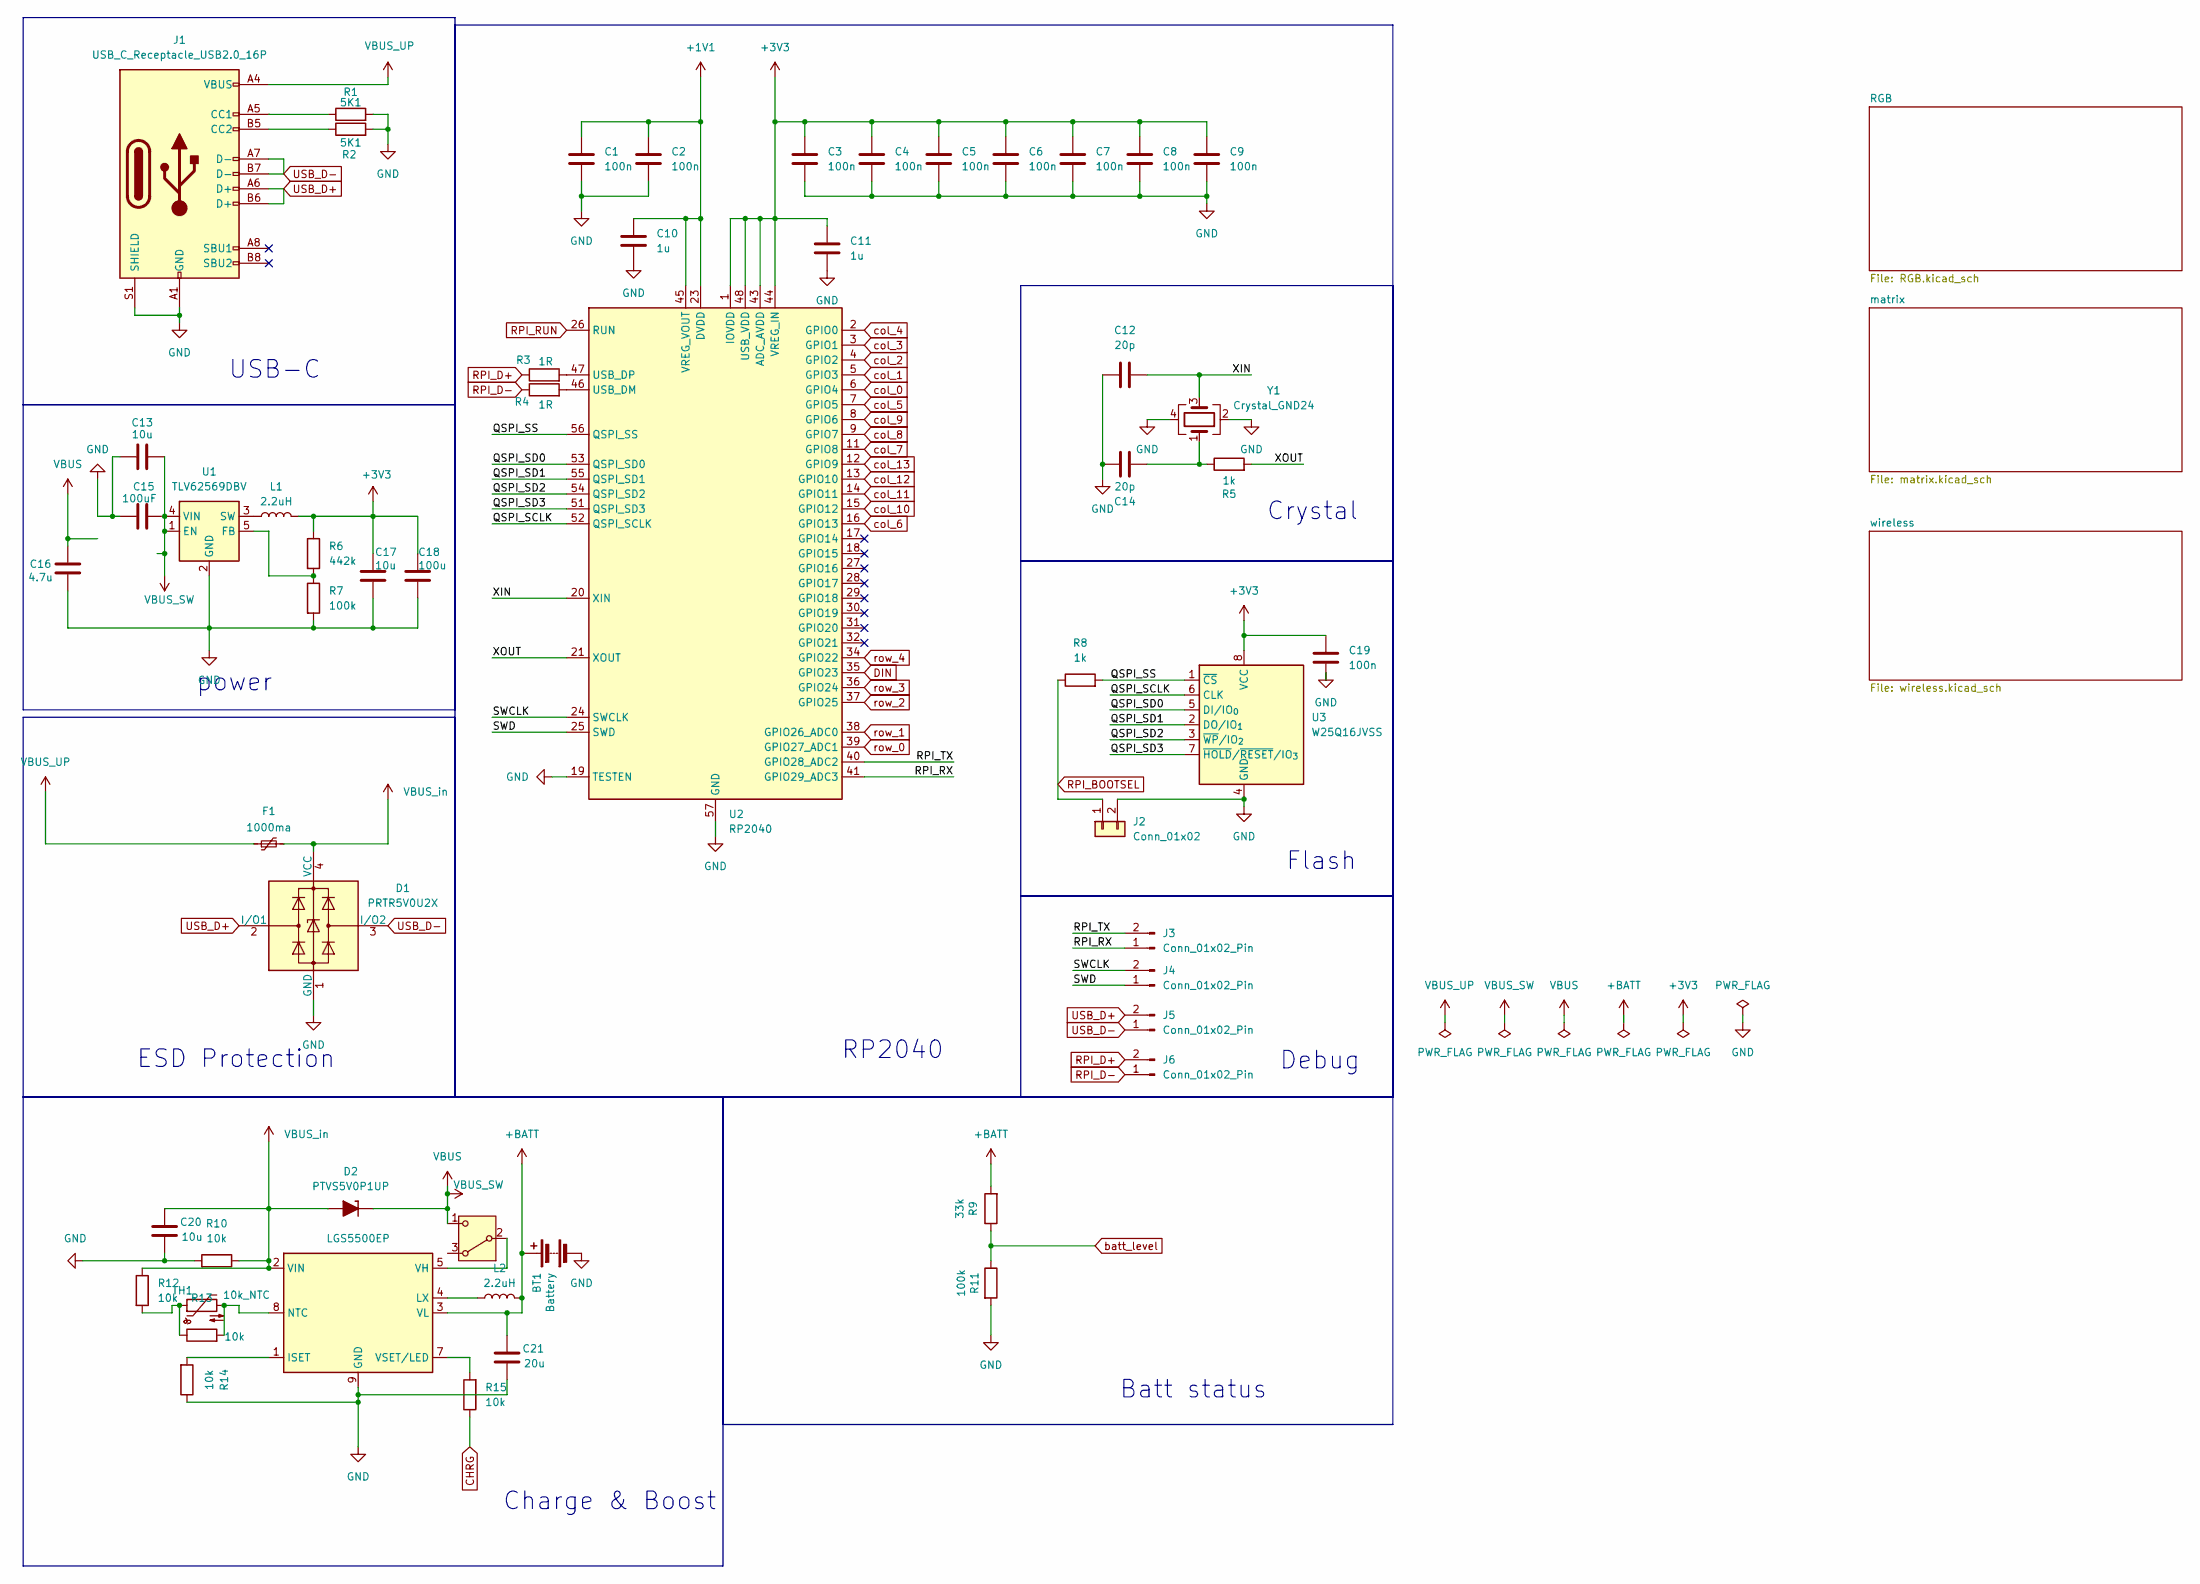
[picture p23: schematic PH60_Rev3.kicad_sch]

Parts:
BT1: Battery; Molex_PicoBlade_53261-0271_1x02-1MP_P1.25mm_Horizontal
C1, C2, C3, C4, C5, C6, C7, C8, C9, C19: 100n; C_0402_1005Metric
C10, C11: 1u; C_0402_1005Metric
C12, C14: 20p; C_0402_1005Metric
C13, C17, C20: 10u; C_0402_1005Metric
C15: 100uF; C_1206_3216Metric
C16: 4.7u; C_0402_1005Metric
C18: 100u; C_0402_1005Metric
C21: 20u; C_0402_1005Metric
D1: PRTR5V0U2X; SOT-143
D2: PTVS5V0P1UP; D_SOD-882_DFN1006-2
F1: 1000ma; Fuse_0805_2012Metric
J1: USB_C_Receptacle_USB2.0_16P; USB-C_16P_HandSolder
J2: Conn_01x02; PinHeader_1x02_P2.54mm_Vertical
J3, J4, J5: Conn_01x02_Pin; PinHeader_1x02_P2.00mm_Vertical
J6: Conn_01x02_Pin; PinHeader_1x02_P1.27mm_Vertical
L1, L2: 2.2uH; L_Changjiang_FNR252012S
R1, R2: 5K1; R_0402_1005Metric
R3, R4: 1R; R_0402_1005Metric
R5, R8: 1k; R_0402_1005Metric
R6: 442k; R_0402_1005Metric
R7, R11: 100k; R_0402_1005Metric
R9: 33k; R_0402_1005Metric
R10, R12, R13, R14, R15: 10k; R_0402_1005Metric
SW1: SW_SPDT_321; SW_MSK12C02-HB
TH1: 10k_NTC; R_0603
U1: TLV62569DBV; SOT-23-5
U2: RP2040; QFN-56-1EP_7x7mm_P0.4mm_EP3.2x3.2mm
U3: W25Q16JVSS; Winbond_USON-8-1EP_3x2mm_P0.5mm_EP0.2x1.6mm
U4: LGS5500EP; SOIC-8-1EP_3.9x4.9mm_P1.27mm_EP2.41x3.3mm
Y1: Crystal_GND24; Crystal_SMD_3225-4Pin_3.2x2.5mm

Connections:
+1V1: C1.1, C2.1, C10.1, U2.23 (DVDD), U2.45 (VREG_VOUT), U2.50 (DVDD)
+3V3: C3.1, C4.1, C5.1, C6.1, C7.1, C8.1, C9.1, C11.1, C17.1, C18.1, C19.1, L1.2, R6.1, U2.1 (IOVDD), U2.10 (IOVDD), U2.22 (IOVDD), U2.33 (IOVDD), U2.42 (IOVDD), U2.43 (ADC_AVDD), U2.44 (VREG_IN), U2.48 (USB_VDD), U2.49 (IOVDD), U3.8 (VCC); also elsewhere on the board
+BATT: BT1.1 (+), C21.1, L2.2, R9.2, U4.3 (VL)
/QSPI_SCLK: U2.52 (QSPI_SCLK), U3.6 (CLK)
/QSPI_SD0: U2.53 (QSPI_SD0), U3.5 (DI/IO_{0})
/QSPI_SD1: U2.55 (QSPI_SD1), U3.2 (DO/IO_{1})
/QSPI_SD2: U2.54 (QSPI_SD2), U3.3 (~WP/IO_{2})
/QSPI_SD3: U2.51 (QSPI_SD3), U3.7 (~HOLD/~RESET/IO_{3})
/QSPI_SS: R8.2, U2.56 (QSPI_SS), U3.1 (~CS)
/RPI_RX: J3.1, U2.41 (GPIO29_ADC3)
/RPI_TX: J3.2, U2.40 (GPIO28_ADC2)
/SWCLK: J4.2, U2.24 (SWCLK)
/SWD: J4.1, U2.25 (SWD)
/XIN: C12.1, U2.20 (XIN), Y1.3
/XOUT: R5.2, U2.21 (XOUT)
CHRG: R15.1; also elsewhere on the board
DIN: U2.35 (GPIO23); also elsewhere on the board
GND: BT1.2 (-), C1.2, C2.2, C3.2, C4.2, C5.2, C6.2, C7.2, C8.2, C9.2, C10.2, C11.2, C12.2, C13.1, C14.2, C15.1, C16.2, C17.2, C18.2, C19.2, C20.2, C21.2, D1.1 (GND), J1.A1 (GND), J1.A12 (GND), J1.B1 (GND), J1.B12 (GND), J1.S1 (SHIELD), J2.2, R1.2, R2.2, R7.2, R10.2, R11.2, R14.1, U1.2 (GND), U2.19 (TESTEN), U2.57 (GND), U3.4 (GND), U4.9 (GND), Y1.2, Y1.4; also elsewhere on the board
unnamed: C14.1, R5.1, Y1.1
unnamed: J1.A5 (CC1), R1.1
unnamed: J1.B5 (CC2), R2.1
unnamed: R12.2, R13.1, TH1.1
unnamed: SW1.2 (B), U4.5 (VH)
unnamed: R6.2, R7.1, U1.5 (FB)
unnamed: L1.1, U1.3 (SW)
unnamed: R4.2, U2.46 (USB_DM)
unnamed: R3.2, U2.47 (USB_DP)
unnamed: R14.2, U4.1 (ISET)
unnamed: L2.1, U4.4 (LX)
unnamed: R13.2, TH1.2, U4.8 (NTC)
unnamed: R15.2, U4.7 (VSET/LED)
RPI_BOOTSEL: J2.1, R8.1; also elsewhere on the board
RPI_D+: J6.2, R3.1; also elsewhere on the board
RPI_D-: J6.1, R4.1; also elsewhere on the board
RPI_RUN: U2.26 (RUN); also elsewhere on the board
USB_D+: D1.2 (I/O1), J1.A6 (D+), J1.B6 (D+), J5.2; also elsewhere on the board
USB_D-: D1.3 (I/O2), J1.A7 (D-), J1.B7 (D-), J5.1; also elsewhere on the board
VBUS: C13.2, C15.2, C16.1, D2.1 (K), SW1.1 (C), U1.1 (EN), U1.4 (VIN); also elsewhere on the board
VBUS_UP: F1.1, J1.A4 (VBUS), J1.A9 (VBUS), J1.B4 (VBUS), J1.B9 (VBUS)
VBUS_in: C20.1, D1.4 (VCC), D2.2 (A), F1.2, R10.1, R12.1, U4.2 (VIN)
batt_level: R9.1, R11.1; also elsewhere on the board
col_0: U2.6 (GPIO4); also elsewhere on the board
col_1: U2.5 (GPIO3); also elsewhere on the board
col_2: U2.4 (GPIO2); also elsewhere on the board
col_3: U2.3 (GPIO1); also elsewhere on the board
col_4: U2.2 (GPIO0); also elsewhere on the board
col_5: U2.7 (GPIO5); also elsewhere on the board
col_6: U2.16 (GPIO13); also elsewhere on the board
col_7: U2.11 (GPIO8); also elsewhere on the board
col_8: U2.9 (GPIO7); also elsewhere on the board
col_9: U2.8 (GPIO6); also elsewhere on the board
col_10: U2.15 (GPIO12); also elsewhere on the board
col_11: U2.14 (GPIO11); also elsewhere on the board
col_12: U2.13 (GPIO10); also elsewhere on the board
col_13: U2.12 (GPIO9); also elsewhere on the board
row_0: U2.39 (GPIO27_ADC1); also elsewhere on the board
row_1: U2.38 (GPIO26_ADC0); also elsewhere on the board
row_2: U2.37 (GPIO25); also elsewhere on the board
row_3: U2.36 (GPIO24); also elsewhere on the board
row_4: U2.34 (GPIO22); also elsewhere on the board

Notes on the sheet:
Batt status
ESD Protection
Charge & Boost
USB-C
Crystal
Flash
power
RP2040
Debug

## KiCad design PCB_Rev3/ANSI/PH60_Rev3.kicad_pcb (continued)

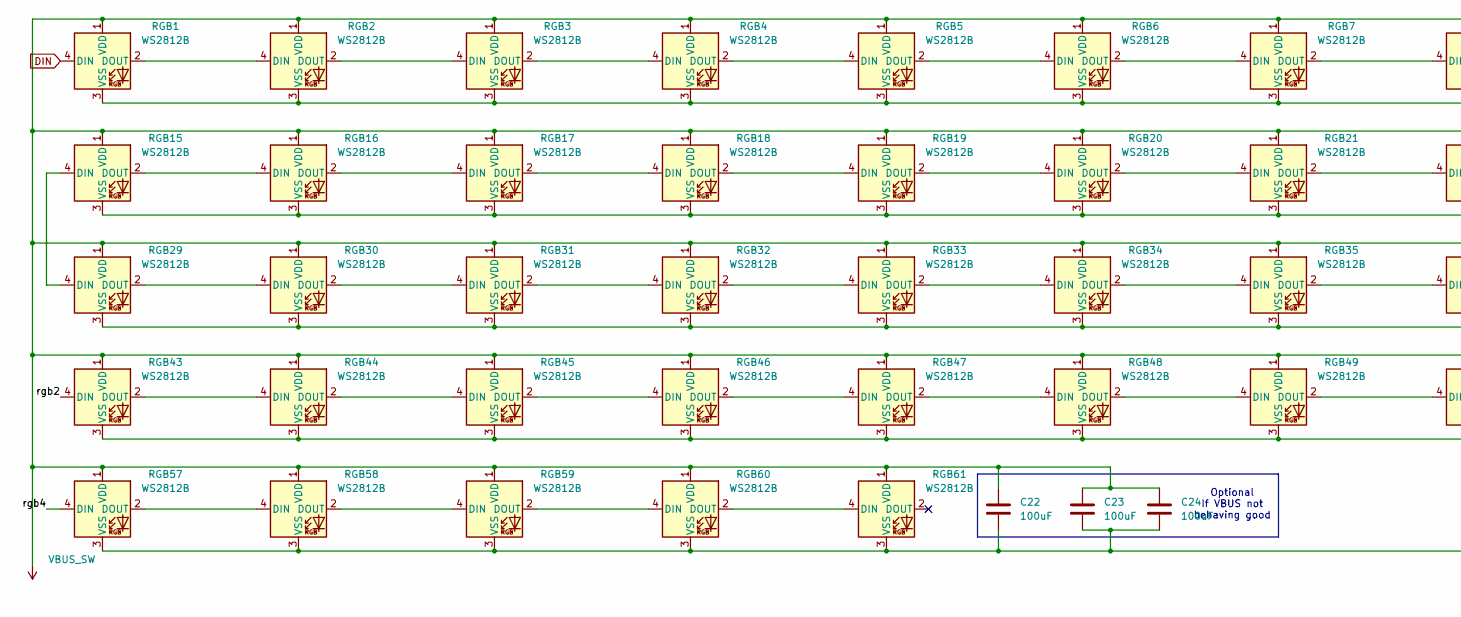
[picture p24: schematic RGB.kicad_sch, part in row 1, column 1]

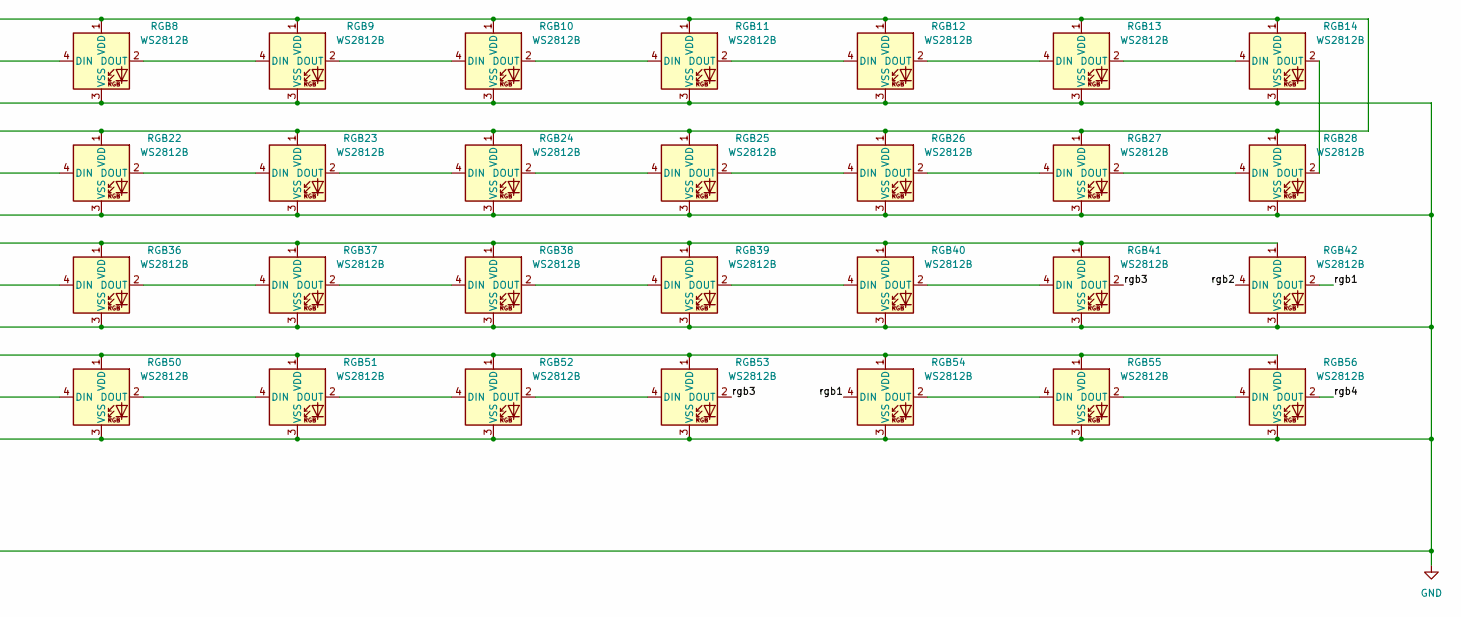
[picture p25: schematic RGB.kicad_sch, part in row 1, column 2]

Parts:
C22, C23, C24: 100uF; C_1206_3216Metric
RGB1, RGB2, RGB3, RGB4, RGB5, RGB6, RGB7, RGB8, RGB9, RGB10, RGB11, RGB12, RGB13, RGB14, RGB15, RGB16, RGB17, RGB18, RGB19, RGB20, RGB21, RGB22, RGB23, RGB24, RGB25, RGB26, RGB27, RGB28, RGB29, RGB30, RGB31, RGB32, RGB33, RGB34, RGB35, RGB36, RGB37, RGB38, RGB39, RGB40, RGB41, RGB42, RGB43, RGB44, RGB45, RGB46, RGB47, RGB48, RGB49, RGB50, RGB51, RGB52, RGB53, RGB54, RGB55, RGB56, RGB57, RGB58, RGB59, RGB60, RGB61: WS2812B; ws2812b_6028

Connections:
/RGB/rgb1: RGB42.2 (DOUT), RGB54.4 (DIN)
/RGB/rgb2: RGB42.4 (DIN), RGB43.4 (DIN)
/RGB/rgb3: RGB41.2 (DOUT), RGB53.2 (DOUT)
/RGB/rgb4: RGB56.2 (DOUT), RGB57.4 (DIN)
DIN: RGB1.4 (DIN); also elsewhere on the board
GND: C22.2, C23.2, C24.2, RGB1.3 (VSS), RGB2.3 (VSS), RGB3.3 (VSS), RGB4.3 (VSS), RGB5.3 (VSS), RGB6.3 (VSS), RGB7.3 (VSS), RGB8.3 (VSS), RGB9.3 (VSS), RGB10.3 (VSS), RGB11.3 (VSS), RGB12.3 (VSS), RGB13.3 (VSS), RGB14.3 (VSS), RGB15.3 (VSS), RGB16.3 (VSS), RGB17.3 (VSS), RGB18.3 (VSS), RGB19.3 (VSS), RGB20.3 (VSS), RGB21.3 (VSS), RGB22.3 (VSS), RGB23.3 (VSS), RGB24.3 (VSS), RGB25.3 (VSS), RGB26.3 (VSS), RGB27.3 (VSS), RGB28.3 (VSS), RGB29.3 (VSS), RGB30.3 (VSS), RGB31.3 (VSS), RGB32.3 (VSS), RGB33.3 (VSS), RGB34.3 (VSS), RGB35.3 (VSS), RGB36.3 (VSS), RGB37.3 (VSS), RGB38.3 (VSS), RGB39.3 (VSS), RGB40.3 (VSS), RGB41.3 (VSS), RGB42.3 (VSS), RGB43.3 (VSS), RGB44.3 (VSS), RGB45.3 (VSS), RGB46.3 (VSS), RGB47.3 (VSS), RGB48.3 (VSS), RGB49.3 (VSS), RGB50.3 (VSS), RGB51.3 (VSS), RGB52.3 (VSS), RGB53.3 (VSS), RGB54.3 (VSS), RGB55.3 (VSS), RGB56.3 (VSS), RGB57.3 (VSS), RGB58.3 (VSS), RGB59.3 (VSS), RGB60.3 (VSS), RGB61.3 (VSS); also elsewhere on the board
unnamed: RGB1.2 (DOUT), RGB2.4 (DIN)
unnamed: RGB2.2 (DOUT), RGB3.4 (DIN)
unnamed: RGB3.2 (DOUT), RGB4.4 (DIN)
unnamed: RGB4.2 (DOUT), RGB5.4 (DIN)
unnamed: RGB5.2 (DOUT), RGB6.4 (DIN)
unnamed: RGB6.2 (DOUT), RGB7.4 (DIN)
unnamed: RGB7.2 (DOUT), RGB8.4 (DIN)
unnamed: RGB8.2 (DOUT), RGB9.4 (DIN)
unnamed: RGB9.2 (DOUT), RGB10.4 (DIN)
unnamed: RGB10.2 (DOUT), RGB11.4 (DIN)
unnamed: RGB11.2 (DOUT), RGB12.4 (DIN)
unnamed: RGB12.2 (DOUT), RGB13.4 (DIN)
unnamed: RGB13.2 (DOUT), RGB14.4 (DIN)
unnamed: RGB14.2 (DOUT), RGB28.2 (DOUT)
unnamed: RGB15.4 (DIN), RGB29.4 (DIN)
unnamed: RGB15.2 (DOUT), RGB16.4 (DIN)
unnamed: RGB16.2 (DOUT), RGB17.4 (DIN)
unnamed: RGB17.2 (DOUT), RGB18.4 (DIN)
unnamed: RGB18.2 (DOUT), RGB19.4 (DIN)
unnamed: RGB19.2 (DOUT), RGB20.4 (DIN)
unnamed: RGB20.2 (DOUT), RGB21.4 (DIN)
unnamed: RGB21.2 (DOUT), RGB22.4 (DIN)
unnamed: RGB22.2 (DOUT), RGB23.4 (DIN)
unnamed: RGB23.2 (DOUT), RGB24.4 (DIN)
unnamed: RGB24.2 (DOUT), RGB25.4 (DIN)
unnamed: RGB25.2 (DOUT), RGB26.4 (DIN)
unnamed: RGB26.2 (DOUT), RGB27.4 (DIN)
unnamed: RGB27.2 (DOUT), RGB28.4 (DIN)
unnamed: RGB29.2 (DOUT), RGB30.4 (DIN)
unnamed: RGB30.2 (DOUT), RGB31.4 (DIN)
unnamed: RGB31.2 (DOUT), RGB32.4 (DIN)
unnamed: RGB32.2 (DOUT), RGB33.4 (DIN)
unnamed: RGB33.2 (DOUT), RGB34.4 (DIN)
unnamed: RGB34.2 (DOUT), RGB35.4 (DIN)
unnamed: RGB35.2 (DOUT), RGB36.4 (DIN)
unnamed: RGB36.2 (DOUT), RGB37.4 (DIN)
unnamed: RGB37.2 (DOUT), RGB38.4 (DIN)
unnamed: RGB38.2 (DOUT), RGB39.4 (DIN)
unnamed: RGB39.2 (DOUT), RGB40.4 (DIN)
unnamed: RGB40.2 (DOUT), RGB41.4 (DIN)
unnamed: RGB43.2 (DOUT), RGB44.4 (DIN)
unnamed: RGB44.2 (DOUT), RGB45.4 (DIN)
unnamed: RGB45.2 (DOUT), RGB46.4 (DIN)
unnamed: RGB46.2 (DOUT), RGB47.4 (DIN)
unnamed: RGB47.2 (DOUT), RGB48.4 (DIN)
unnamed: RGB48.2 (DOUT), RGB49.4 (DIN)
unnamed: RGB49.2 (DOUT), RGB50.4 (DIN)
unnamed: RGB50.2 (DOUT), RGB51.4 (DIN)
unnamed: RGB51.2 (DOUT), RGB52.4 (DIN)
unnamed: RGB52.2 (DOUT), RGB53.4 (DIN)
unnamed: RGB54.2 (DOUT), RGB55.4 (DIN)
unnamed: RGB55.2 (DOUT), RGB56.4 (DIN)
unnamed: RGB57.2 (DOUT), RGB58.4 (DIN)
unnamed: RGB58.2 (DOUT), RGB59.4 (DIN)
unnamed: RGB59.2 (DOUT), RGB60.4 (DIN)
unnamed: RGB60.2 (DOUT), RGB61.4 (DIN)
VBUS: C22.1, C23.1, C24.1, RGB1.1 (VDD), RGB2.1 (VDD), RGB3.1 (VDD), RGB4.1 (VDD), RGB5.1 (VDD), RGB6.1 (VDD), RGB7.1 (VDD), RGB8.1 (VDD), RGB9.1 (VDD), RGB10.1 (VDD), RGB11.1 (VDD), RGB12.1 (VDD), RGB13.1 (VDD), RGB14.1 (VDD), RGB15.1 (VDD), RGB16.1 (VDD), RGB17.1 (VDD), RGB18.1 (VDD), RGB19.1 (VDD), RGB20.1 (VDD), RGB21.1 (VDD), RGB22.1 (VDD), RGB23.1 (VDD), RGB24.1 (VDD), RGB25.1 (VDD), RGB26.1 (VDD), RGB27.1 (VDD), RGB28.1 (VDD), RGB29.1 (VDD), RGB30.1 (VDD), RGB31.1 (VDD), RGB32.1 (VDD), RGB33.1 (VDD), RGB34.1 (VDD), RGB35.1 (VDD), RGB36.1 (VDD), RGB37.1 (VDD), RGB38.1 (VDD), RGB39.1 (VDD), RGB40.1 (VDD), RGB41.1 (VDD), RGB42.1 (VDD), RGB43.1 (VDD), RGB44.1 (VDD), RGB45.1 (VDD), RGB46.1 (VDD), RGB47.1 (VDD), RGB48.1 (VDD), RGB49.1 (VDD), RGB50.1 (VDD), RGB51.1 (VDD), RGB52.1 (VDD), RGB53.1 (VDD), RGB54.1 (VDD), RGB55.1 (VDD), RGB56.1 (VDD), RGB57.1 (VDD), RGB58.1 (VDD), RGB59.1 (VDD), RGB60.1 (VDD), RGB61.1 (VDD); also elsewhere on the board

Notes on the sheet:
Optional If VBUS not behaving good

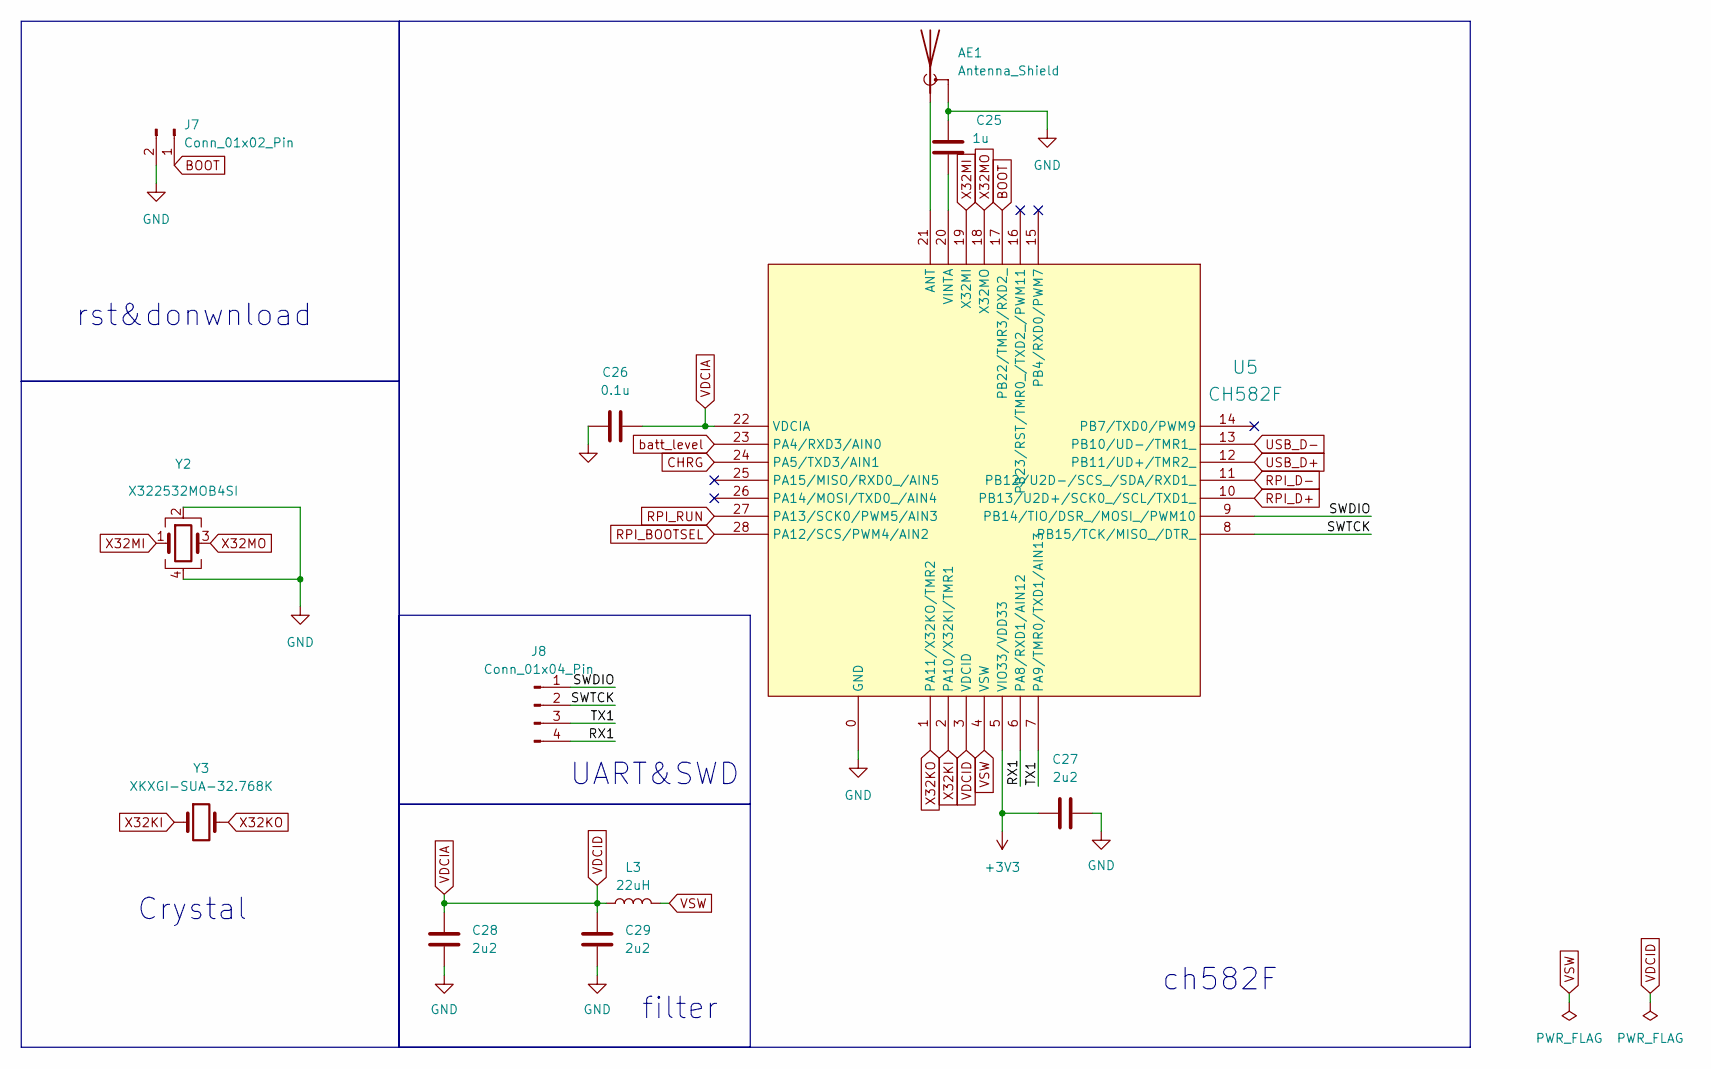
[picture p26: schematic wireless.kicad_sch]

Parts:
AE1: Antenna_Shield; ANT-2.4G-1.6MM-MINI-Reversed
C25: 1u; C_0402_1005Metric
C26: 0.1u; C_0402_1005Metric
C27, C28, C29: 2u2; C_0402_1005Metric
J7: Conn_01x02_Pin; PinHeader_1x02_P2.00mm_Vertical
J8: Conn_01x04_Pin; PinHeader_1x04_P2.00mm_Vertical
L3: 22uH; L_Changjiang_FNR252012S
U5: CH582F; QFN28_4X4_FIX
Y2: X322532MOB4SI; Crystal_SMD_3225-4Pin_3.2x2.5mm
Y3: XKXGI-SUA-32.768K; Crystal_SMD_3215-2Pin_3.2x1.5mm

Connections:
+3V3: C27.1, U5.5 (VIO33/VDD33); also elsewhere on the board
/wireless/RX1: J8.4, U5.6 (PA8/RXD1/AIN12)
/wireless/SWDIO: J8.1, U5.9 (PB14/TIO/DSR_/MOSI_/PWM10)
/wireless/SWTCK: J8.2, U5.8 (PB15/TCK/MISO_/DTR_)
/wireless/TX1: J8.3, U5.7 (PA9/TMR0/TXD1/AIN13)
BOOT: J7.1, U5.17 (PB22/TMR3/RXD2_)
CHRG: U5.24 (PA5/TXD3/AIN1); also elsewhere on the board
GND: AE1.2 (Shield), C25.1, C26.1, C27.2, C28.2, C29.2, J7.2, U5.0 (GND), Y2.2, Y2.4; also elsewhere on the board
unnamed: AE1.1 (A), U5.21 (ANT)
unnamed: C25.2, U5.20 (VINTA)
RPI_BOOTSEL: U5.28 (PA12/SCS/PWM4/AIN2); also elsewhere on the board
RPI_D+: U5.10 (PB13/U2D+/SCK0_/SCL/TXD1_); also elsewhere on the board
RPI_D-: U5.11 (PB12/U2D-/SCS_/SDA/RXD1_); also elsewhere on the board
RPI_RUN: U5.27 (PA13/SCK0/PWM5/AIN3); also elsewhere on the board
USB_D+: U5.12 (PB11/UD+/TMR2_); also elsewhere on the board
USB_D-: U5.13 (PB10/UD-/TMR1_); also elsewhere on the board
VDCIA: C26.2, C28.1, C29.1, L3.1, U5.3 (VDCID), U5.22 (VDCIA)
VSW: L3.2, U5.4 (VSW)
X32KI: U5.2 (PA10/X32KI/TMR1), Y3.1
X32KO: U5.1 (PA11/X32KO/TMR2), Y3.2
X32MI: U5.19 (X32MI), Y2.1
X32MO: U5.18 (X32MO), Y2.3
batt_level: U5.23 (PA4/RXD3/AIN0); also elsewhere on the board

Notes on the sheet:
filter
Crystal
rst&donwnload
ch582F
UART&SWD

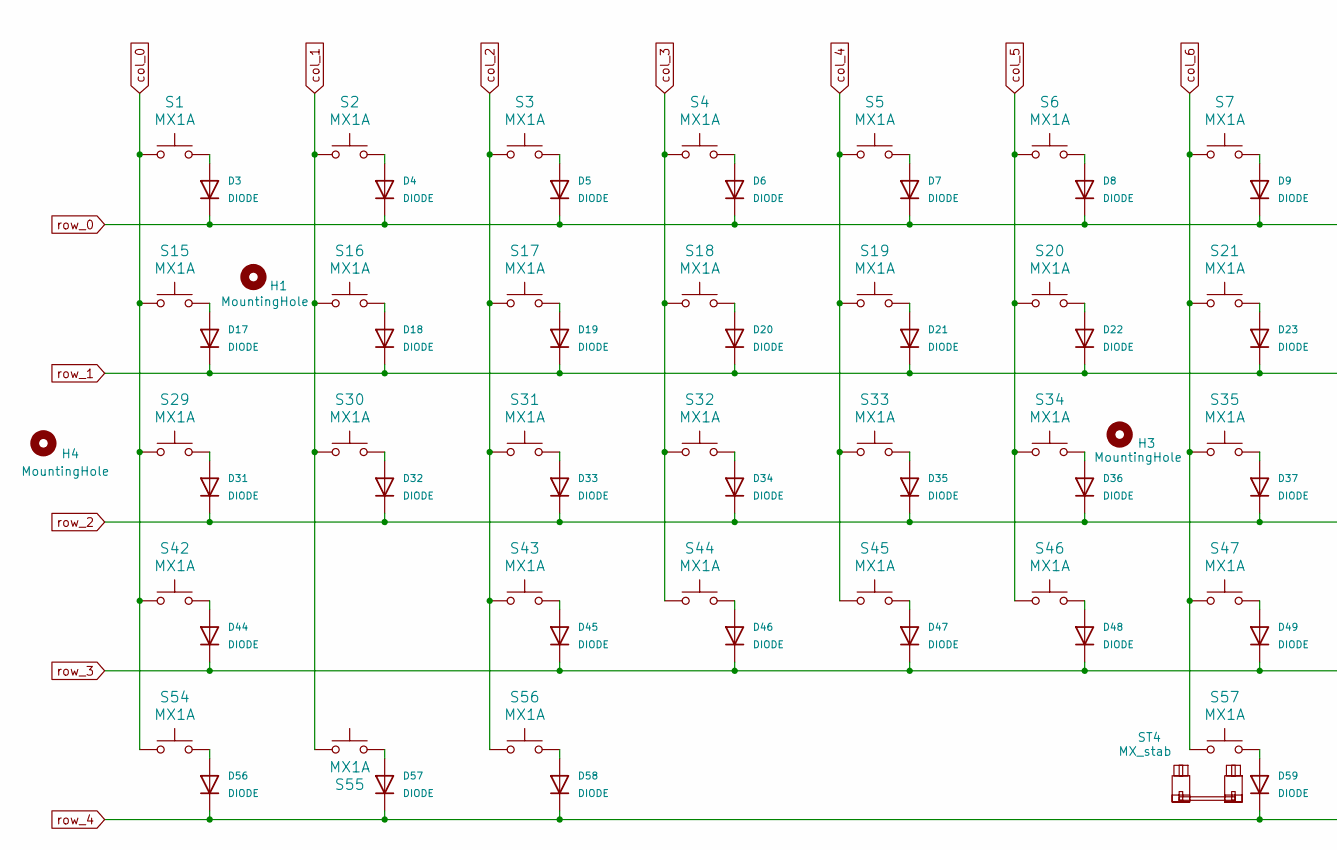
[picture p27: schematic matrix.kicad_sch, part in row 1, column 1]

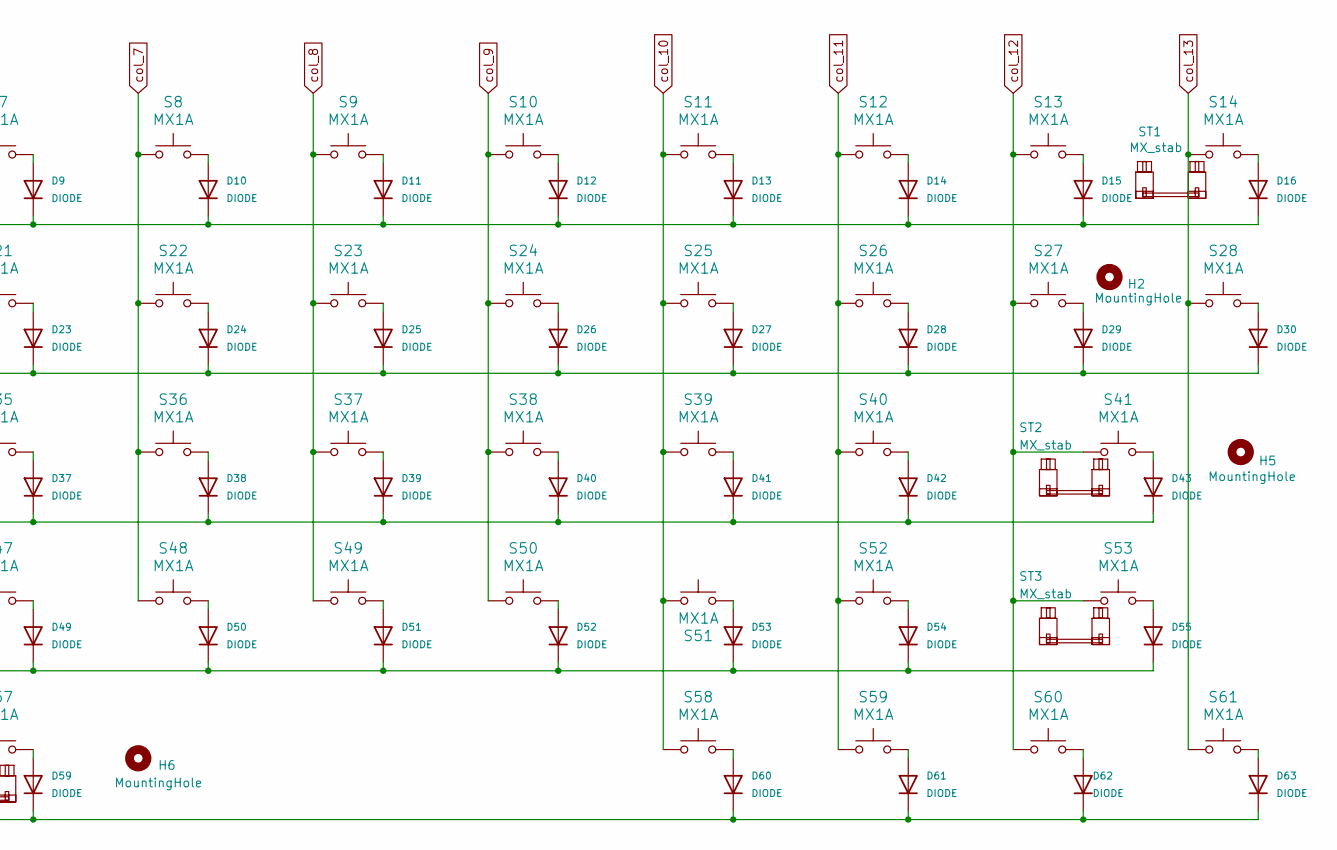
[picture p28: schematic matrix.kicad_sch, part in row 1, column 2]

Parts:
D3, D4, D5, D6, D7, D8, D9, D10, D11, D12, D13, D14, D15, D16, D17, D18, D19, D20, D21, D22, D23, D24, D25, D26, D27, D28, D29, D30, D31, D32, D33, D34, D35, D36, D37, D38, D39, D40, D41, D42, D43, D44, D45, D46, D47, D48, D49, D50, D51, D52, D53, D54, D55, D56, D57, D58, D59, D60, D61, D62, D63: DIODE; D_SOD-323_HandSoldering
H1: MountingHole; PKRHC
H2, H6: MountingHole; PKRH
H3: MountingHole; PKRHHALF
H4, H5: MountingHole; PKRHSL
S1, S2, S3, S4, S5, S6, S7, S8, S9, S10, S11, S12, S13, S16, S17, S18, S19, S20, S21, S22, S23, S24, S25, S26, S27, S30, S31, S32, S33, S34, S35, S36, S37, S38, S39, S40, S43, S44, S45, S46, S47, S48, S49, S50, S51, S52: MX1A; SW_Hotswap_Kailh_MX_Plated_1.00u
S14: MX1A; SW_Hotswap_Kailh_MX_Plated_2.00u
S15, S28: MX1A; SW_Hotswap_Kailh_MX_Plated_1.50u
S29: MX1A; SW_Hotswap_Kailh_MX_Plated_1.75u
S41, S42: MX1A; SW_Hotswap_Kailh_MX_Plated_2.25u
S53: MX1A; SW_Hotswap_Kailh_MX_Plated_2.75u
S54, S55, S56, S58, S59, S60, S61: MX1A; SW_Hotswap_Kailh_MX_Plated_1.25u
S57: MX1A; SW_Hotswap_Kailh_MX_Plated_6.25u
ST1, ST2, ST3: MX_stab; Stabilizer_Cherry_MX_2.00u
ST4: MX_stab; Stabilizer_Cherry_MX_6.25u

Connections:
unnamed: D3.2 (A), S1.1
unnamed: D4.2 (A), S2.1
unnamed: D5.2 (A), S3.1
unnamed: D6.2 (A), S4.1
unnamed: D7.2 (A), S5.1
unnamed: D8.2 (A), S6.1
unnamed: D9.2 (A), S7.1
unnamed: D10.2 (A), S8.1
unnamed: D11.2 (A), S9.1
unnamed: D12.2 (A), S10.1
unnamed: D13.2 (A), S11.1
unnamed: D14.2 (A), S12.1
unnamed: D15.2 (A), S13.1
unnamed: D16.2 (A), S14.1
unnamed: D17.2 (A), S15.1
unnamed: D18.2 (A), S16.1
unnamed: D19.2 (A), S17.1
unnamed: D20.2 (A), S18.1
unnamed: D21.2 (A), S19.1
unnamed: D22.2 (A), S20.1
unnamed: D23.2 (A), S21.1
unnamed: D24.2 (A), S22.1
unnamed: D25.2 (A), S23.1
unnamed: D26.2 (A), S24.1
unnamed: D27.2 (A), S25.1
unnamed: D28.2 (A), S26.1
unnamed: D29.2 (A), S27.1
unnamed: D30.2 (A), S28.1
unnamed: D31.2 (A), S29.1
unnamed: D32.2 (A), S30.1
unnamed: D33.2 (A), S31.1
unnamed: D34.2 (A), S32.1
unnamed: D35.2 (A), S33.1
unnamed: D36.2 (A), S34.1
unnamed: D37.2 (A), S35.1
unnamed: D38.2 (A), S36.1
unnamed: D39.2 (A), S37.1
unnamed: D40.2 (A), S38.1
unnamed: D41.2 (A), S39.1
unnamed: D42.2 (A), S40.1
unnamed: D43.2 (A), S41.1
unnamed: D44.2 (A), S42.1
unnamed: D45.2 (A), S43.1
unnamed: D46.2 (A), S44.1
unnamed: D47.2 (A), S45.1
unnamed: D48.2 (A), S46.1
unnamed: D49.2 (A), S47.1
unnamed: D50.2 (A), S48.1
unnamed: D51.2 (A), S49.1
unnamed: D52.2 (A), S50.1
unnamed: D53.2 (A), S51.1
unnamed: D54.2 (A), S52.1
unnamed: D55.2 (A), S53.1
unnamed: D56.2 (A), S54.1
unnamed: D57.2 (A), S55.1
unnamed: D58.2 (A), S56.1
unnamed: D59.2 (A), S57.1
unnamed: D60.2 (A), S58.1
unnamed: D61.2 (A), S59.1
unnamed: D62.2 (A), S60.1
unnamed: D63.2 (A), S61.1
col_0: S1.2, S15.2, S29.2, S42.2, S54.2; also elsewhere on the board
col_1: S2.2, S16.2, S30.2, S55.2; also elsewhere on the board
col_2: S3.2, S17.2, S31.2, S43.2, S56.2; also elsewhere on the board
col_3: S4.2, S18.2, S32.2, S44.2; also elsewhere on the board
col_4: S5.2, S19.2, S33.2, S45.2; also elsewhere on the board
col_5: S6.2, S20.2, S34.2, S46.2; also elsewhere on the board
col_6: S7.2, S21.2, S35.2, S47.2, S57.2; also elsewhere on the board
col_7: S8.2, S22.2, S36.2, S48.2; also elsewhere on the board
col_8: S9.2, S23.2, S37.2, S49.2; also elsewhere on the board
col_9: S10.2, S24.2, S38.2, S50.2; also elsewhere on the board
col_10: S11.2, S25.2, S39.2, S51.2, S58.2; also elsewhere on the board
col_11: S12.2, S26.2, S40.2, S52.2, S59.2; also elsewhere on the board
col_12: S13.2, S27.2, S41.2, S53.2, S60.2; also elsewhere on the board
col_13: S14.2, S28.2, S61.2; also elsewhere on the board
row_0: D3.1 (K), D4.1 (K), D5.1 (K), D6.1 (K), D7.1 (K), D8.1 (K), D9.1 (K), D10.1 (K), D11.1 (K), D12.1 (K), D13.1 (K), D14.1 (K), D15.1 (K), D16.1 (K); also elsewhere on the board
row_1: D17.1 (K), D18.1 (K), D19.1 (K), D20.1 (K), D21.1 (K), D22.1 (K), D23.1 (K), D24.1 (K), D25.1 (K), D26.1 (K), D27.1 (K), D28.1 (K), D29.1 (K), D30.1 (K); also elsewhere on the board
row_2: D31.1 (K), D32.1 (K), D33.1 (K), D34.1 (K), D35.1 (K), D36.1 (K), D37.1 (K), D38.1 (K), D39.1 (K), D40.1 (K), D41.1 (K), D42.1 (K), D43.1 (K); also elsewhere on the board
row_3: D44.1 (K), D45.1 (K), D46.1 (K), D47.1 (K), D48.1 (K), D49.1 (K), D50.1 (K), D51.1 (K), D52.1 (K), D53.1 (K), D54.1 (K), D55.1 (K); also elsewhere on the board
row_4: D56.1 (K), D57.1 (K), D58.1 (K), D59.1 (K), D60.1 (K), D61.1 (K), D62.1 (K), D63.1 (K); also elsewhere on the board

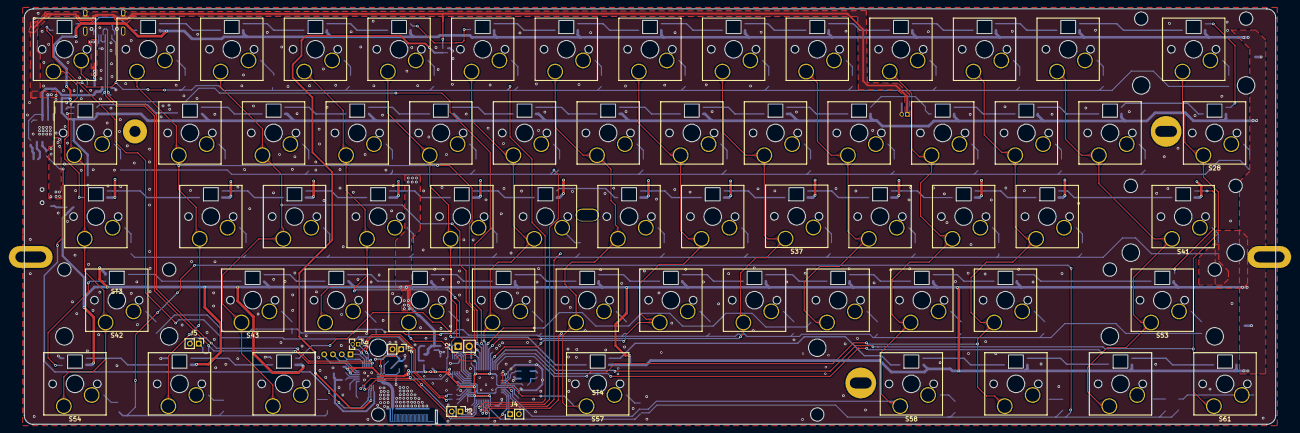
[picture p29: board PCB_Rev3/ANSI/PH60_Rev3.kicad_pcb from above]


Board: 2 copper layers, 285.0 x 94.6 mm, 264 parts (186 on the bottom side), 194 nets.

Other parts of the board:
ST0: Stabilizer_Cherry_MX_2.00u

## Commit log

2026-04-19 Initial commit for PH60 Rev.3
    [BOM-PH60_Rev3.csv, CHXXX.pcblib, CHXXX.schlib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]
2026-05-30 Update inner_case_left.step
    Remove slot for power switch
    [inner_case_left.step]
